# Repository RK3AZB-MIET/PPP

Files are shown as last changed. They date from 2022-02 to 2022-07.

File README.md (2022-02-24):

# Радиоприёмник прямого преобразования (приёмник Полякова)

Характеристики

Диапазон: 40 м (7000…7200 кГц), двухполосный приём (DSB)
Напряжение питания: 9 В («Крона»)
Ток потребления: ~15 мА
Выход: низкоомные наушники или малогабаритный динамик
Габариты: 100х50х75 мм (без выступающих ручек и разъёмов)

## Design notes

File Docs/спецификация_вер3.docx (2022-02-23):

СПЕЦИФИКАЦИЯ

ВЕРСИЯ 3.1

11

Наименование | Обозначение | Номинал | Кол-во

Конденсаторы
Конденсатор керамический 22пф 50V | C2 | 22pF | 1
Конденсатор керамический 100пф 50v NPO | C1, C7 | 100pF | 2
Конденсатор керамический 150пФ 50v NPO | C10 | 150pF | 1
Конденсатор керамический 180пф 50v М1500 | C8 | 180pF | 1
Конденсатор керамический 220пф 50V NPO | C1’, C2’ | 220pF | 2
Конденсатор керамический 4700пФ М1500 | C11 | 4700pF | 1
Конденсатор керамический 0.01мкф 50V X7R | C13 | 10nF | 1
Конденсатор керамический 0.047мкф 50v X7R | C9 | 47nF | 1
Конденсатор керамический 0.1мкф 50v Y5V | C3’, C3, C5, C6, C12, C16, C17, C18 | 100nF | 8
Конденсатор электролитический 10мкф 63V | C4, C14 | 10uF | 2
Конденсатор электролитический 100мкф 25V | C15 | 100uF | 1
Конденсатор электролитический 470мкф 16V | C20, C22 | 470uF | 2

Резисторы постоянные
Резистор 47 Ом 0.125Вт | R18 | 47 | 1
Резистор 470 Ом 0.25Вт | R14 | 470 | 1
Резистор 1.0 КОм 0.25Вт | R2’, R7 | 1k | 2
Резистор 2.0 КОм 0.25Вт | R10, R11, R12, R16 | 2k | 4
Резистор 3.3 кОм 0.25Вт | R2 | 3.3k | 1
Резистор 4.7 КОм 0.25Вт | R15, R19 | 4.7k | 2
Резистор 10 КОм 0.25Вт | R1 | 10k | 1
Резистор 15 КОм 0.25Вт | R1’ | 15k | 1
Резистор 20 КОм 0.25Вт | R6 | 20k | 1
Резистор 51 КОм 0.25Вт | R20 | 51k | 1
Резистор 100 КОм 0.25Вт | R5, R9 | 100k | 2
Резистор 200 КОм 0.25Вт | R8 | 200k | 1
Резистор 1 МОм 0.25Вт | R17 | 1M | 1
Резистор 2.2 МОм 0.25Вт | R17 | 2.2M | 1

Полупроводниковые приборы
BC547B (NPN 45V 0.1A 0.63W) TO-92 | VT1’, VT2, VT3, VT4, VT5 | | 5
BC557B (PNP 45V 0.1A 0.5W) TO-92 | VT1, VT6 | | 2
78L06ACZ Стабилизатор напряжения (+6В; 0.1А) TO-92 | DA1 | | 1
1N4148 (0.15A 100V) DO-35 | VD1, VD2 | | 2
1N4007 (1А 1000В) DO-41 | VD3 | | 1
Светодиод 3мм зеленый | - | | 1

Прочее
Батарейный отсек Крона BS-E провод 100мм | XP2 | | 1
Гнездо на плату 3.5мм CKX3-3.5-01 | XS1 | | 1
Разъем BNC гнездо на корпус | XT1 | | 1
Ручка приборная MF-B02 | - | | 1
Ручка приборная RR4836 зеленая (круг, 6мм) | - | | 2
Переменный резистор S16KN1-B 10K L15F с выключателем | R13 | 10k | 1
Переменный резистор 16K1 (WH148) 10k шлиц | R4 | 10k | 1
Переменный резистор 16K1 (WH148) 1k шлиц | R3 | 1k | 1
Кнопка тактовая 6*6*4.3 KAN0611-0431B | SB1*’ | | 1
Каркас катушки | L1, L2 | | 2
Резонатор кварцевый 7.000 МГц | ZQ1’ | | 1
B64290-L38-X38, T38, R10х6х4, Сердечник ферритовый кольцевой | L3 | | 1

ПЕРЕЧЕНЬ ИЗМЕНЕНИЙ

Обозначение | Наименование по спецификации | Наименование замены

СХЕМА ЭЛЕКТРИЧЕСКАЯ ПРИНЦИПИАЛЬНАЯ

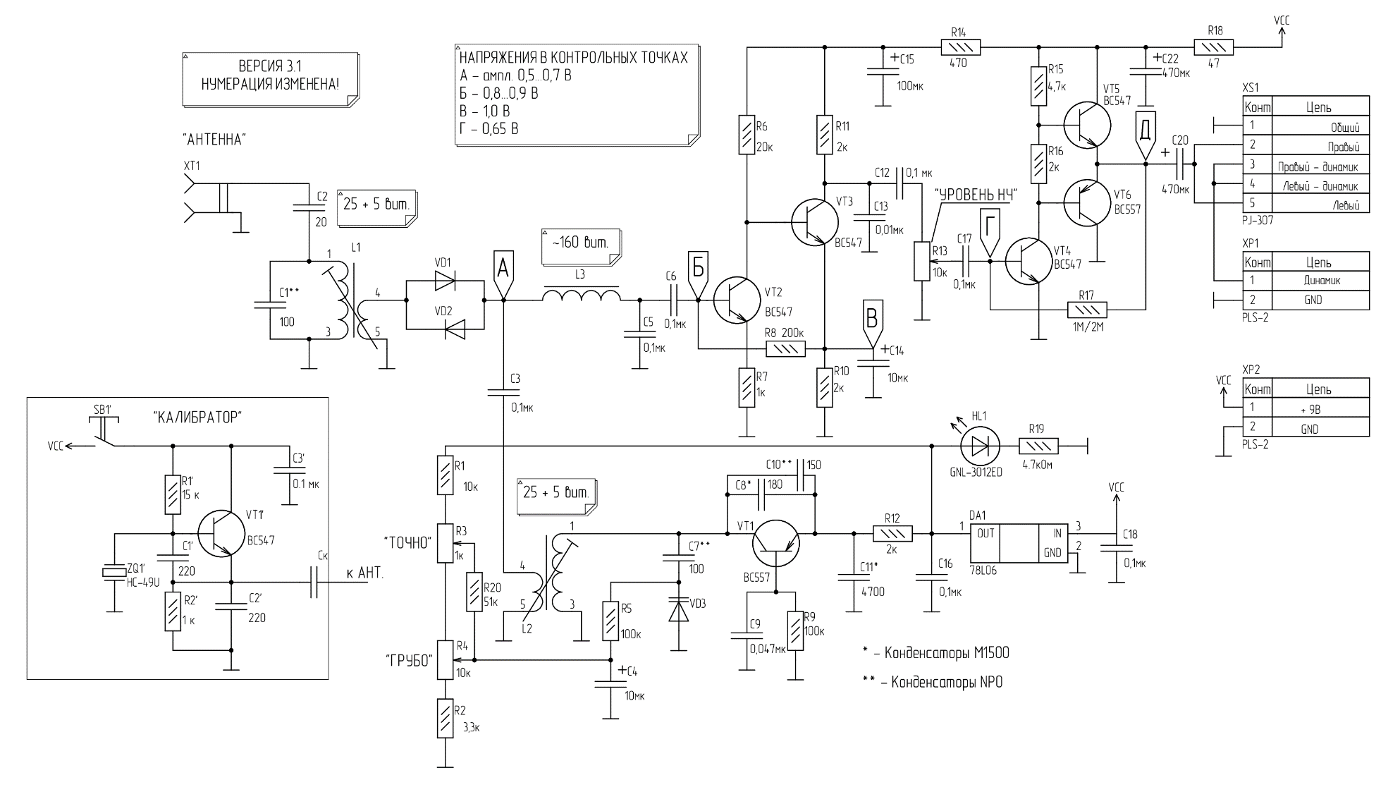
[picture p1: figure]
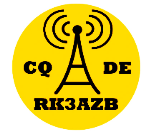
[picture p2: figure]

РАДИОКЛУБ МИЭТ г.ЗЕЛЕНОГРАД 73 DE RK3AZB!

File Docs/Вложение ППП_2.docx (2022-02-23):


Версия 3

РАДИОКЛУБ МИЭТ

РАДИОПРИЕМНИК ПРЯМОГО ПРЕОБРАЗОВАНИЯ

Перечень элементов

Обозначение | Номинал | Описание | Кол-во
C1, C2 | 180 или 220 | Конденсатор керамический | 2
C11, C16 | 0,01мк | Конденсатор керамический | 2
C12 | 180 | Конденсатор керамический М1500 | 1
C14 | 150 | Конденсатор керамический NP0 | 1
C13 | 0,047мк | Конденсатор керамический | 1
C15 | 4700 | Конденсатор керамический М1500 | 1
C17 | 47мк | Конденсатор электролитический | 1
C22, C23 | 470мк | Конденсатор электролитический | 2
C3 | 10 | Конденсатор керамический | 1
C4, C7, C9, C10, C19, C20, C21, C24 | 0,1мк | Конденсатор керамический | 8
C5 | 100 | Конденсатор керамический | 1
C6 | 22 | Конденсатор керамический | 1
C8 | 10мк | Конденсатор электролитический | 1
C18 | 100мк | Конденсатор электролитический | 1
DA1 | 78L06 | Стабилизатор напряжения | 1
L1, L2 | - | Катушка индуктивности подстроечная | 2
L3 | - | Катушка индуктивности | 1
R1 | 15к | Резистор | 1
R11, R12, R13, R17 | 2к | Резистор | 4
R15 | 470 | Резистор | 1
R16 | 4,7к | Резистор | 1
R18 | 2,2М | Резистор | 1
R19 | 47 | Резистор | 1
R2, R3, R8 | 1к | Резистор | 3
R4 | 1к | Резистор переменный | 1
R5 | 10к | Резистор переменный | 1
R14 | 10к | Резистор переменный с выключателем | 1
R6, R10 | 100к | Резистор | 2
R7 | 20к | Резистор | 1
R9 | 200к | Резистор | 1
SB1 | KLS7-TS6601 | Кнопка тактовая | 1
VD1, VD2 | 1N4148 | Диод | 2
VD3, VD4 | BB133 | Варикап | 2
VT1, VT3, VT4, VT5, VT6 | BC547 | Транзистор биполярный | 5
VT2, VT7 | BC557 | Транзистор биполярный | 2
XP1, XP2* | PLS-2 | Вилка штыревая | 2
XS1 | PJ-307 | Розетка | 1
XT1* | DG128-5.0-02P-14 | Соединитель | 1
ZQ1 | 7 (7.03) MГц | Резонатор кварцевый | 1

Дополнительно: розетка BNC, рукоятки малые (2 шт), рукоятка большая, колодка батарейная, светодиод, резистор 4,7к для светодиода

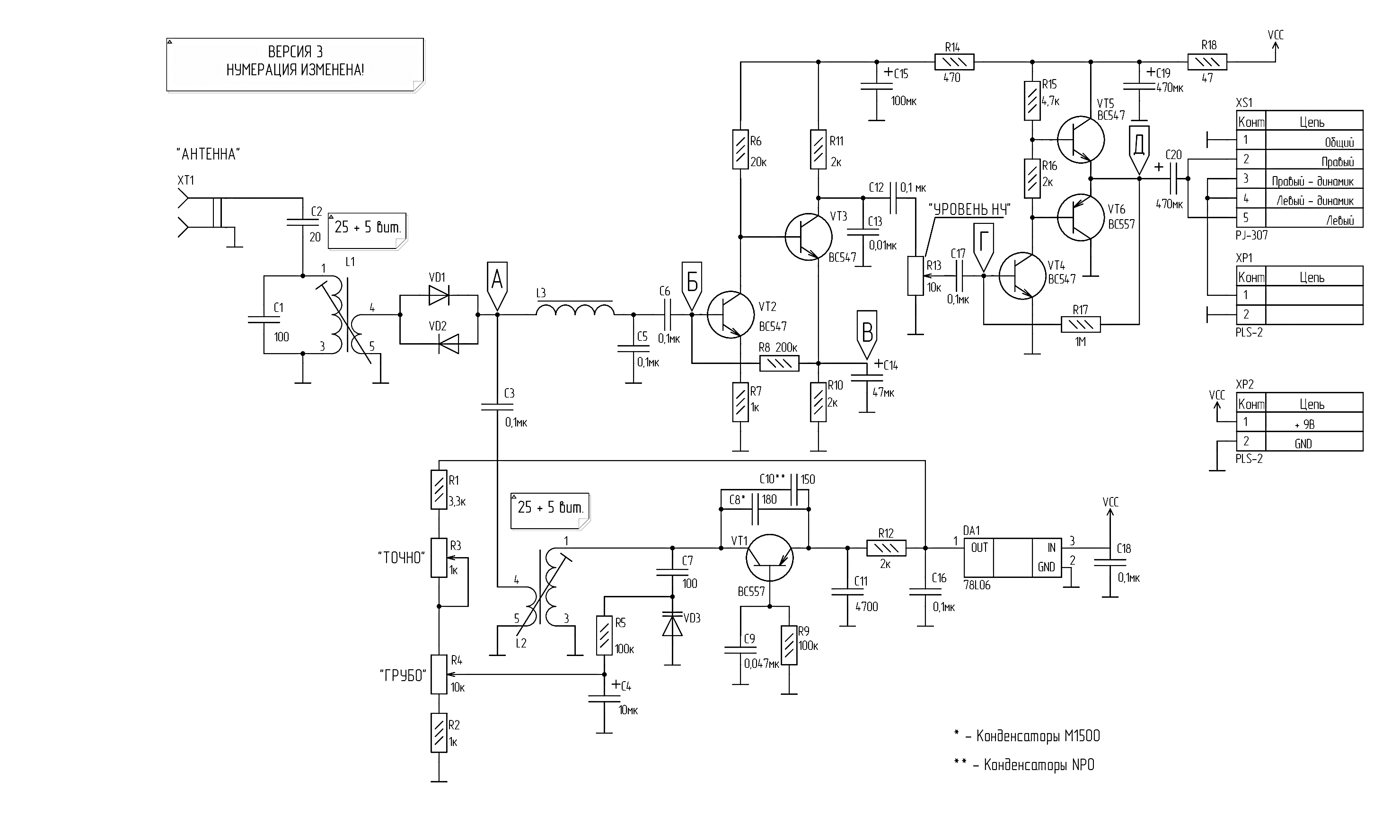
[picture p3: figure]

Схема базовая.

Версия 3

Напряжения в контр. точках

A | ампл. 0,5…0,7 В
Б | 0,8…0,9 В
B | 1,0…1,1 В
Г | 0,65 В
Д | 4,5 В

Благодарим вас за внимание к нашему проекту! Желаем получить удовольствие от сборки и наладки приемника. 73 de R2DNN, R3YAB

Схема калибратора.

Схема шкалы цифровой.

Замена ЭРИ

Поз. обозначение | Номинал в схеме | Замена

__________ * - не комплектовать

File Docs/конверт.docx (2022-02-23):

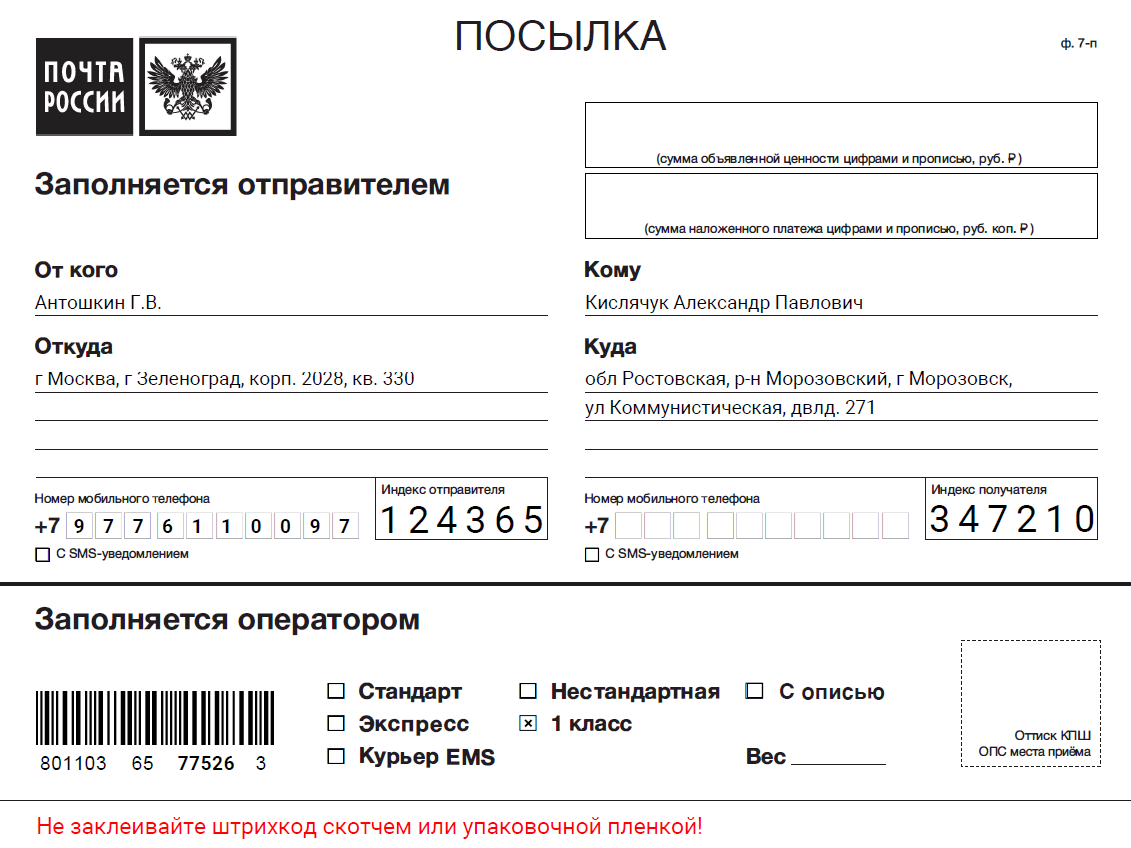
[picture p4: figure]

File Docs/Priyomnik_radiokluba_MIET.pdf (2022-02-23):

РАДИОКЛУБ МИЭТ

## Радиоприемник прямого преобразования

## (Радиоприёмник В.Т. Полякова)

Инструкция по сборке и наладке

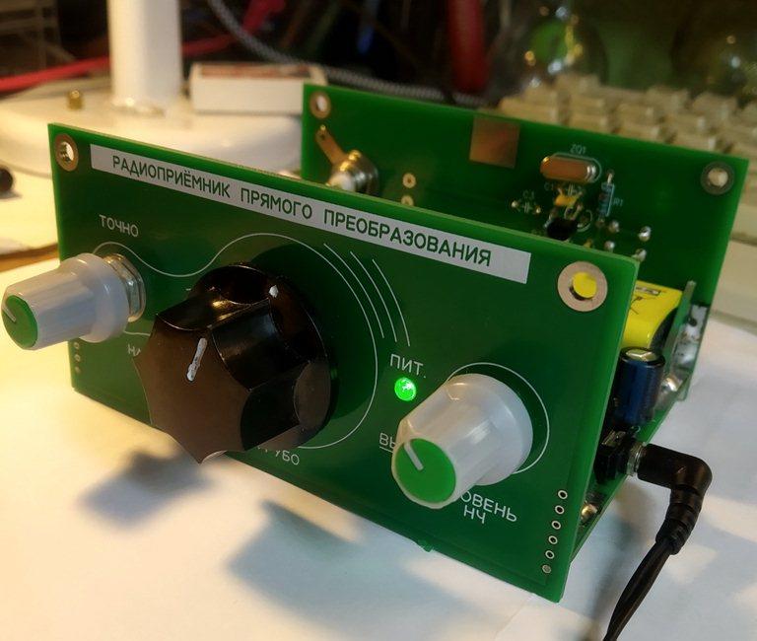
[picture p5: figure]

Зеленоград 2020

Здравствуйте!

Итак, Вы получили комплект для сборки приёмника прямого преобразования радиоклуба МИЭТ. Здесь мы опишем его схему, шаги по сборке и настройке.

Характеристики

Диапазон: 40 м (7000…7200 кГц), двухполосный приём (DSB)

Напряжение питания: 9 В («Крона»)

Ток потребления: ~15 мА

Выход: низкоомные наушники или малогабаритный динамик

Схема

Приёмник сделан на основе классических схем прямого преобразования [1, 2]. Гетеродин - плавного диапазона (ГПД) с регулировкой варикапами.

В колебательный контур гетеродина входят L2 (первичная обмотка) и (VD3+VD4)–C11–(C12+C14)–C15, причем цепочки емкостей (VD3+VD4)–C11 и (C12+C14)–C15 входят в контур параллельно. Ёмкость контура определяют VD3+VD4 (переменная часть) и C12+C14 (постоянная часть). Цепочка резисторов R3-R5-R4 создает отрицательное смещение на варикапах VD3+VD4 и позволяет регулировать частоту – грубо и плавно. Гетеродин настроен на половинную частоту диапазона и перестраивается от 3500 до 3600 кГц с небольшим запасом сверху и снизу. Питание гетеродина 6 В стабилизировано DA1 и блокировочными конденсаторами C19 и С21.

Простой входной контур L1C5 связан с антенной через небольшую ёмкость C6 и со смесителем через вторичную обмотку L1 – так согласовывается высокое сопротивление контура с низким сопротивлением смесителя и антенны.

Смеситель на встречно-параллельных диодах VD1-VD2 (1N4148) позволяет выделять разностную частоту между частотой сигнала и удвоенной частотой гетеродина.

Через конденсатор C7 сигнал гетеродина со вторичной обмотки L2 поступает на смеситель, и тот же C7 входит в состав фильтра низкой частоты (ФНЧ) C7L3C9 с частотой среза около 3 кГц, что позволяет комфортно слушать SSB станции.

УНЧ состоит из предусилителя (VT3-VT4) и усилителя мощности (VT5-VT6-VT7), разделённых регулятором громкости. Выход и вход предусилителя связан отрицательной обратной связью (ООС) R9, которая выставляет режим транзисторов по постоянному току. Конденсатор C17 ослабляет ООС по звуковой частоте, что поднимает коэффициент усиления. Конденсатор C16 вместе с выходным сопротивлением предусилителя и регулятором громкости R14 образует дополнительный ФНЧ, ослабляя мешающие сигналы в районе нескольких килогерц.

После регулятора громкости сигнал усиливается усилителем мощности на двух каскадах, причём второй каскад – эмиттерный повторитель на транзисторах разной проводимости. С точки соединения эмиттеров VT6 и VT7 сигнал, с одной стороны, поступает через R18 на вход, образуя ООС усилителя мощности (так образуется смещение на базе транзистора VT5), а, с другой – идёт на низкоомную нагрузку через разделительный конденсатор C23. Цепочки C18 R15, C22 R19 развязывают по питанию каскады УНЧ друг от друга и от гетеродина, препятствуя самовозбуждению.

Детали и наладка

Прежде всего собирают УНЧ и проверяют его работу, подключив наушники и включив питание через миллиамперметр. Нормально работающий УНЧ должен потреблять около 10 мА, при этом в наушниках должен быть слышен белый шум. Если коснуться пинцетом входа УНЧ (левый по схеме вывод C20), в наушниках будет громкий фон 50 Гц. Вольтметром измеряется напряжение в точке Д соединения эмиттеров VT6–VT7 – оно должно быть равно половине напряжения питания. Также проверяются контрольные напряжения в точках Б (0,8…0,9 В), В (1,0 В), Г (0,65 В). Если при работающем УНЧ ток покоя значительно больше 10 мА (20…30 мА), то стоит его уменьшить, увеличив значение резистора R18, например, до 2 МОм. Поскольку схема и конструкция приёмника рассчитаны на маломощную «Крону», то лучше сделать приёмник максимально экономичным. Выходной каскад VT6–VT7 является главным потребителем тока в приёмнике, и коэффициент усиления этих транзисторов, во-первых, должен быть примерно одинаков, а, во-вторых, он совместно с R18 и определяет потребляемый ток.

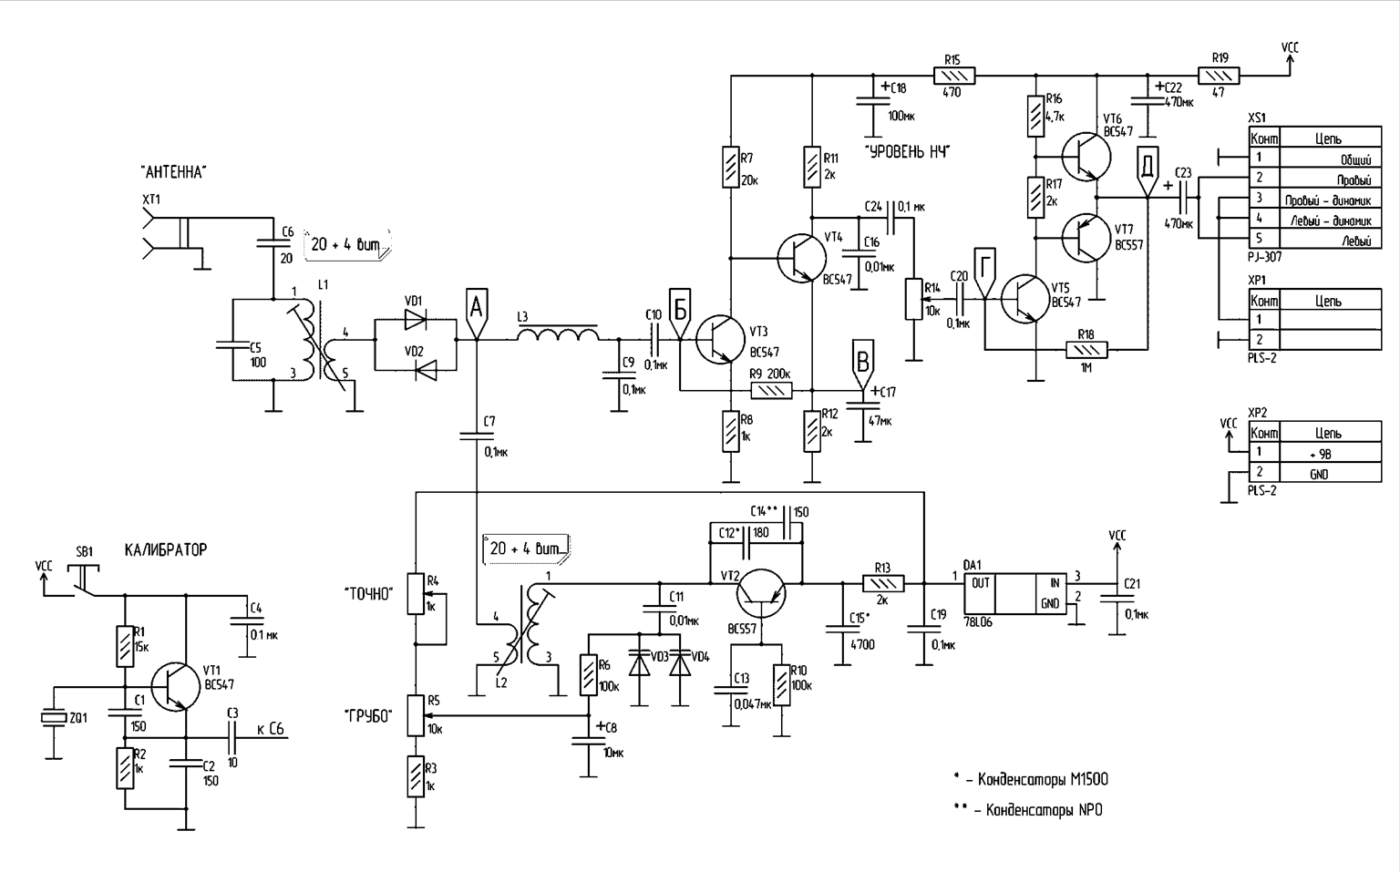
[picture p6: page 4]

4

Рис. 1. Схема электрическая принципиальная

Усиление УНЧ получается с запасом, его хватает и на работу динамика. Если всё же предполагается использовать наушники, а сигнал получается слишком громким и/или усилитель самовозбуждается, рекомендуем заменить значение R8 на большее, например, 2…4,7 кОм – это снизит коэффициент усиления.

Дроссель L3 наматывают на входящем в набор ферритовом сердечнике с проницаемостью 10000 размером 10х6х4. С помощью челнока наматывают 200 витков (это соответствует индуктивности 0,16 Гн). Еще один вариант -использовать головку от магнитофона. Также интересны недавно появившиеся сердечники из аморфного железа (см. статью [3]), тогда число витков будет сильно меньше. L4 закрепляют на плате термоклеем.

Затем можно приступать к гетеродину, смесителю и входному контуру. Катушки L1 и L2 – одинаковые, они наматываются на каркасах диаметром 5 мм с ферритовым подстроечным сердечником эмалированным проводом 0,11 мм (намоточный провод длиной 3 м входит в комплект – его хватает на L1, L2 и L3). Для первичной обмотки 20 витков, для вторичной – 4 витка. Первичную катушку лучше мотать виток к витку, туго прижимая витки к каркасу и друг к другу. Крайние витки можно закреплять нитками, а можно воспользоваться хитростями промышленных технологий ручной намотки (рис. 2): вырезается тонкая полоска плотной бумаги шириной примерно 1 мм и длиной около 2 см. Прежде чем намотать первый виток на катушку, один виток провода завязывают вокруг это полоски у ее края. Прикладывают эту полоску к катушке – вдоль каркаса, так чтобы маленькая петля была у основания катушки – так закрепляется первый виток. Затем плотно наматывают первичную катушку, начиная от этой петельки, чтобы полоска бумаги была плотно прижата намоткой к каркасу. Последний виток также закрепляют в виде петельки вокруг бумажной полоски. Аналогично делают вторичную обмотку на расстоянии 1…2 миллиметров от первичной. В конце желательно закрепить обмотки парафином, лишние хвостики бумажной полоски обрезают.

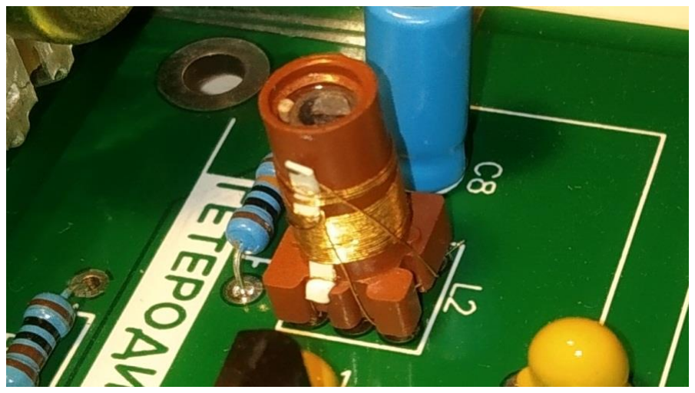
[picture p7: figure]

Рис. 2. Фиксация намотки на каркасе.

Довольно тонкой работы требуют SMD варикапы BB133 (рис. 3), они паяются снизу основной платы. Перед пайкой стоит определить их полярность мультиметром в режиме проверки диодов. При пайке лучше использовать лупу и тонкий пинцет.

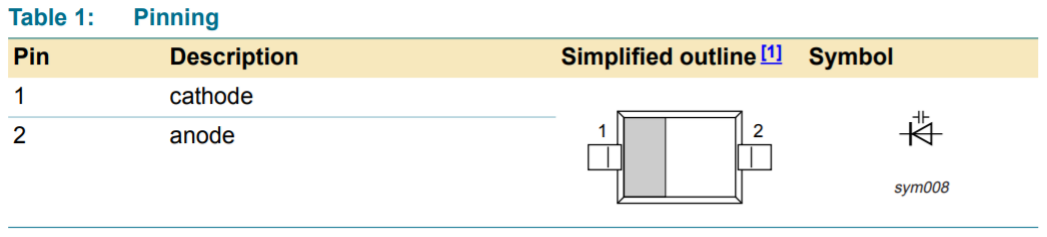
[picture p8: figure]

Рис. 3. Расположение выводов варикапа BB133

После того, как приёмник спаян полностью, проверяют работу гетеродина с помощью осциллографа (при его наличии), либо сделав простейший пробник из германиевого диода, последовательно соединенного с вольтметром – так можно оценивать амплитуду переменного напряжения в различных точках схемы. В точке А измеряют амплитуду переменного напряжения – оно должно быть около 0,5…0,7 В (среднее значение должно быть равно 0).

Далее необходимо отрегулировать рабочий диапазон гетеродина. Можно воспользоваться осциллографом или частотомером, но удобнее использовать калибратор с кварцевой стабилизацией на 7000 кГц в составе приёмника (см. схему). При вывернутых влево ручках настройки собираемого приёмника (нижний край диапазона) вращением сердечника катушки L2 находят частоту 7000 кГц (частота гетеродина 3500 кГц).

Затем поворачиваем ручку грубой настройки вправо – смотрим, какая частота получается. В идеале должно быть около 7220…7240 кГц (оставляем по десять-двадцать килогерц запас сверху и снизу). Верхний край диапазона можно найти в вечернее время с подключенной антенной – сразу после любительского диапазона начинается вещательный диапазон, на нижнем краю которого (начиная с 7205 кГц) обычно работают громкие вещательные станции. Ширину диапазона можно сделать такой, чтобы можно было настроиться на несущую одной из таких станций.

Если диапазон получается слишком широким или слишком узким, надо подобрать значение конденсаторов C12 и C14. Ещё один способ регулировки ширины диапазона: изменить значение эмиттерного резистора R13. Дело в том, что при этом будет меняться амплитуда сигнала гетеродина, а она будет влиять на эффективную ёмкость варикапов: чем больше R13, тем меньше амплитуда, и тем больше эффективный интервал перестройки варикапов, шире диапазон. В пределах амплитуды 0,5…0,7 вольт в точке А смеситель будет работать хорошо, и некоторый запас в вариации амплитуды гетеродина обычно есть. И, наконец, можно также увеличить значение сопротивления R3 до нескольких килоом в случае слишком широкого диапазона.

Обратите внимание: в комплект входят конденсаторы колебательного контура гетеродина с нормируемыми ТКЕ (температурный коэффициент ёмкости). Варикапы и катушка имеют положительный температурный коэффициент, и их надо компенсировать отрицательными ТКЕ C12-C14. Для этого в двух из них стоит ТКЕ М1500 (-1500 ppm на градус), а в третьем NP0 (нулевой температурный коэффициент).

При желании можно измерить такой параметр приёмника, как уход частоты при изменении температуры. Проверять этот параметр лучше после того, как приёмник остынет после пайки. Потребуется термометр, небольшая картонная коробка и какой-либо источник тепла либо холода. Включённый приёмник вместе с термометром закрывают в коробку и дают частоте и температуре внутри застабилизироваться вдали от источника тепла или холода. Замечают частоту гетеродина внешним приёмником, и записывают температуру. Затем переносят коробку на подоконник (если на улице холодно) или ставят на нагреватель, и дожидаются установки новой стабильной частоты и новой стабильной
температуры. | Достаточно | перепада | температуры | около | 10 | °C. | Для
использования приёмника в домашних условиях желательно добиться, чтобы частота уходила не больше нескольких сотен Гц/°C. Значения вложенных в набор конденсаторов C12-C14 удовлетворяют этим требованиям.

В конце, подключив антенну, регулируют входной контур подстройкой ферритового сердечника L1 по максимуму громкости сигнала или шума в середине диапазона, затем еще раз точно выставляют начало диапазона катушкой L2, и отладка приёмника завершена.

Конструкция и порядок сборки

Приёмник выполнен в виде трёх плат, которые собираются пайкой в жёсткую конструкцию. Сначала собирают основную плату, проверяют работу УНЧ и гетеродина – эти узлы начинают работать и без переменных резисторов. Затем собирают переднюю панель – прикручивают переменные резисторы (R14 – с выключателем) и припаивают их ножки к контактам на плате (ножки нужно пригнуть к плате пинцетом). Светодиод припаивают к контактным площадкам и соединяют анод через резистор 4.7К к выключателю питанию на потенциометре громкости R14, к тому же контакту выключателя идёт провод к «+» XP2 на основной плате. Плюсовой вывод от батареи питания припаивают ко второму контакту выключателя, минусовой – к «-» XP2. Передняя панель припаивается снизу контактными площадками.

Затем собирается калибратор, прикручивается антенный разъём, припаивается его центральный контакт коротким проводом к контакту X1 на плате, и задняя панель также припаивается снизу контактами к основной плате. В таком положении приёмник можно настраивать, а при крайней необходимости переднюю и заднюю платы несложно отпаять.

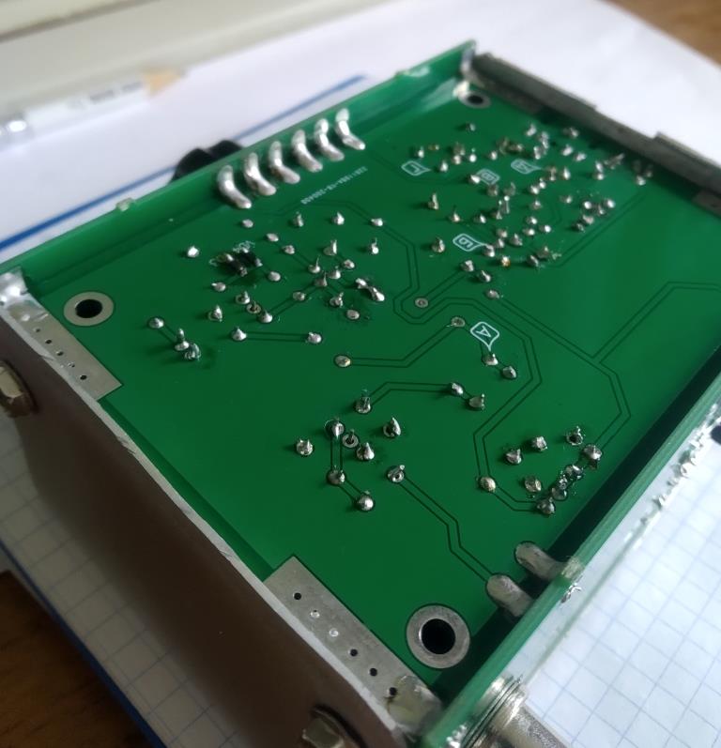
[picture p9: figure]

Рис. 4. Вид снизу на монтаж радиоприемника.

Наконец, после окончательной настройки на диапазон выравнивают положение плат друг относительно друга (под углом 90˚) и припаивают уголки. «Крону» можно прикрепить к основной плате двусторонним скотчем.

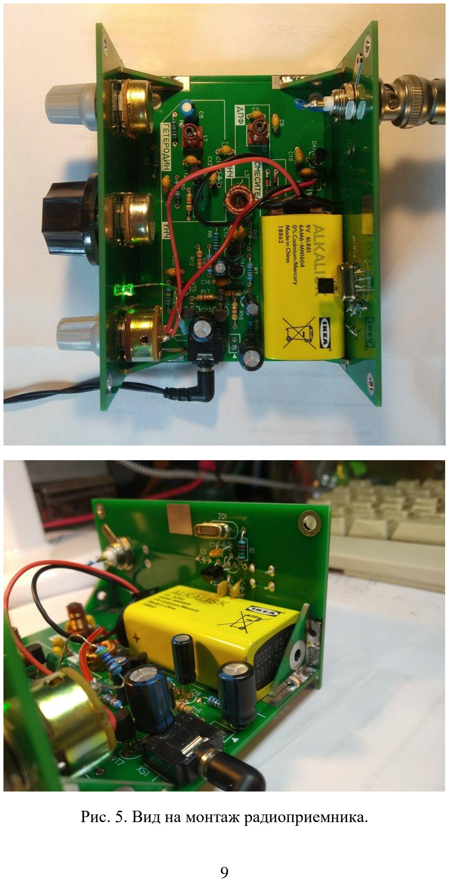
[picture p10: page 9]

Рис. 5. Вид на монтаж радиоприемника.

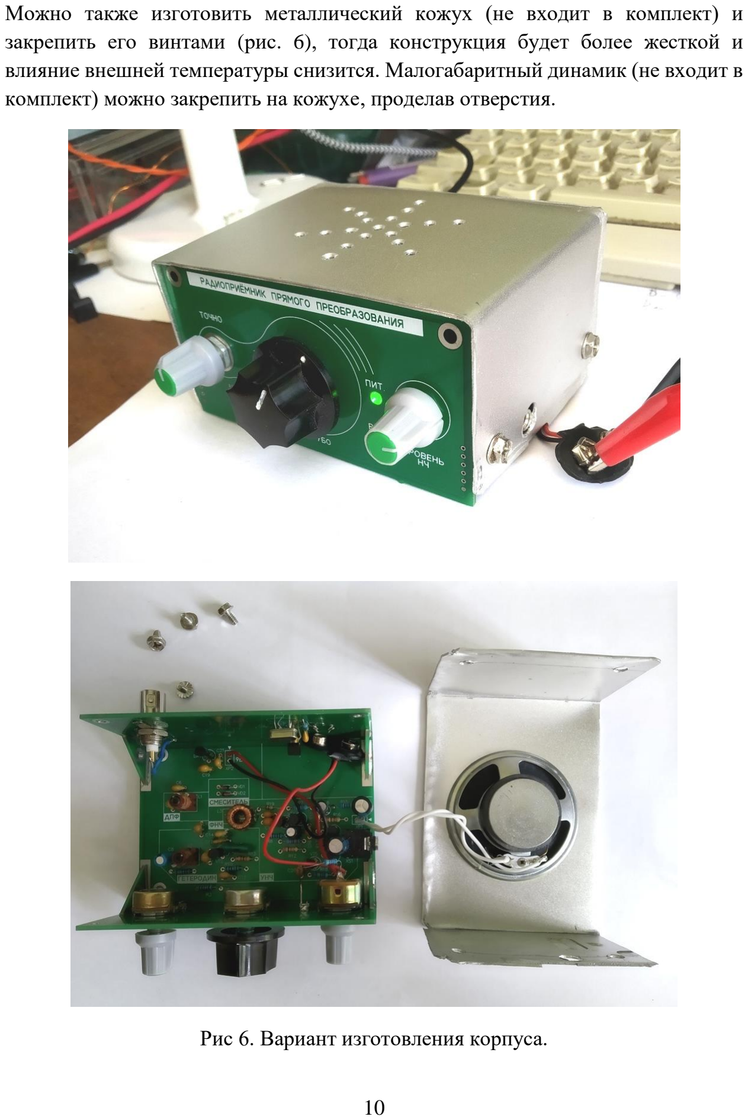
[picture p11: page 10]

Можно также изготовить металлический кожух (не входит в комплект) и закрепить его винтами (рис. 6), тогда конструкция будет более жесткой и влияние внешней температуры снизится. Малогабаритный динамик (не входит в комплект) можно закрепить на кожухе, проделав отверстия.

Рис 6. Вариант изготовления корпуса.

Благодарим вас за внимание к нашему проекту! Желаем получить удовольствие от сборки и наладки приемника. 73!

С любыми вопросами обращайтесь:

Влад Жигалов (R2DNN) zhigalov@gmail.com

Герман Антошкин (R3YAB) r3yab@mail.ru

Радиоклуб МИЭТ (RK3AZB) https://vk.com/rk3azb

Литература:

1. В.Т. Поляков. Радиолюбителям о технике прямого преобразования (1990). http://qrp.ru/files/literature/category/10-ra3aaedocs?download=247%3Adc
2. В.Т. Поляков. Приемник прямого преобразования для "охоты на лис", журнал "Радио" за 1982 год, №4, стр. 49-52; №7, стр.54, 55. http://qrp.ru/files/literature/category/10-ra3aaedocs?download=376%3Afoxhuntdcrra3aae (http://qrp.ru/files/literature/category/10-ra3aaedocs?download=376%3Afoxhuntdcrra3aae)
3. Д. Горох. Применение сердечников из аморфного железа. CQ-QRP#70 (Весна 2020). http://qrp.ru/cqqrp-magazine/1536-cq-qrp-70
4. Тема про данный приёмник на форуме клуба RU-QRP: RU-QRP Club forum :: Тема: Приёмник ППП радиоклуба МИЭТ (http://qrp.ru/forum/9-%D0%A1%D0%B0%D0%BC%D0%BE%D0%B4%D0%B5%D0%BB%D1%8C%D0%BD%D0%B0%D1%8F-%D1%82%D0%B5%D1%85%D0%BD%D0%B8%D0%BA%D0%B0/13210-%D0%9F%D1%80%D0%B8%D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)

Приложение. Перечень элементов

Обозначение | Номинал | Описание | Кол-во
C1, C2 | 180 или 220 | Конденсатор керамический | 2
C11, C16 | 0.01мк | Конденсатор керамический | 2
C12 | 180 | Конденсатор керамический М1500 | 1
C14 | 150 | Конденсатор керамический NP0 | 1
C13 | 0,047мк | Конденсатор керамический | 1
C15 | 4700 | Конденсатор керамический М1500 | 1
C17 | 47мк | Конденсатор электролитический | 1
C22, C23 | 470мк | Конденсатор электролитический | 2
C3 | 10 | Конденсатор керамический | 1
C4, C7, C9, C10, C19, C20, C21, C24 | 0.1мк | Конденсатор керамический | 8
C5 | 100 | Конденсатор керамический | 1
C6 | 22 | Конденсатор керамический | 1
C8 | 10мк | Конденсатор электролитический | 1
C18 | 100мк | Конденсатор электролитический | 1
DA1 | 78L06 | Стабилизатор напряжения | 1
L1, L2 | - | Катушка индуктивности подстроечная | 2
L3 | - | Катушка индуктивности | 1
R1 | 15к | Резистор | 1
R11, R12, R13, R17 | 2к | Резистор | 4
R15 | 470 | Резистор | 1
R16 | 4.7к | Резистор | 1
R18 | 1М или 2М | Резистор | 1
R19 | 47 | Резистор | 1
R2, R3, R8 | 1к | Резистор | 3
R4 | 1к | Резистор переменный | 1
R5, R14 | 10к | Резистор переменный c выключателем | 2
R6, R10 | 100к | Резистор | 2
R7 | 20к | Резистор | 1
R9 | 200к | Резистор | 1
SB1 | KLS7-TS6601 | Кнопка тактовая | 1
VD1, VD2 | 1N4148 | Диод | 2
VD3, VD4 | BB133 | Варикап | 2
VT1, VT3, VT4, VT5, VT6 | BC547 | Транзистор биполярный | 5
VT2, VT7 | BC557 | Транзистор биполярный | 2
XP1, XP2* | PLS-2 | Вилка штыревая | 2
XS1 | PJ-307 | Розетка | 1
XT1* | DG128-5.0-02P-14 | Соединитель | 1
ZQ1 | 7 MHz | Резонатор кварцевый | 1
* - не комплектуются

Дополнительно: розетка BNC, рукоятки малые (2 шт), рукоятка большая, колодка батарейная, светодиод, резистор 4,7к для светодиода.

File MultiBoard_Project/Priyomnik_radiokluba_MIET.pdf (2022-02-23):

РАДИОКЛУБ МИЭТ

## Радиоприемник прямого преобразования

## (Радиоприёмник В.Т. Полякова)

Инструкция по сборке и наладке


Зеленоград 2020

Добрый день!

Итак, Вы получили комплект для сборки приёмника прямого преобразования радиоклуба МИЭТ. Здесь мы опишем его схему, шаги по сборке и настройке.

Характеристики

Диапазон: 40 м (7000…7200 кГц), двухполосный приём (DSB)

Напряжение питания: 9 В («Крона»)

Ток потребления: ~15 мА

Выход: низкоомные наушники или малогабаритный динамик

Схема

Приёмник сделан на основе классических схем прямого преобразования [1, 2]. Гетеродин - плавного диапазона (ГПД) с регулировкой варикапами.

В колебательный контур гетеродина входят L2 (первичная обмотка) и (VD3+VD4)–C11–(C12+C14)–C15, причем цепочки емкостей (VD3+VD4)–C11 и (C12+C14)–C15 входят в контур параллельно. Ёмкость контура определяют VD3+VD4 (переменная часть) и C12+C14 (постоянная часть). Цепочка резисторов R3-R5-R4 создает отрицательное смещение на варикапах VD3+VD4 и позволяет регулировать частоту – грубо и плавно. Гетеродин настроен на половинную частоту диапазона и перестраивается от 3500 до 3600 кГц с небольшим запасом сверху и снизу. Питание гетеродина 6 В стабилизировано DA1 и блокировочными конденсаторами C19 и С21.

Простой входной контур L1C5 связан с антенной через небольшую ёмкость C6 и со смесителем через вторичную обмотку L1 – так согласовывается высокое сопротивление контура с низким сопротивлением смесителя и антенны.

Смеситель на встречно-параллельных диодах VD1-VD2 (1N4148) позволяет выделять разностную частоту между частотой сигнала и удвоенной частотой гетеродина.

Через конденсатор C7 сигнал гетеродина со вторичной обмотки L2 поступает на смеситель, и тот же C7 входит в состав фильтра низкой частоты (ФНЧ) C7L3C9 с частотой среза около 3 кГц, что позволяет комфортно слушать SSB станции.

УНЧ состоит из предусилителя (VT3-VT4) и усилителя мощности (VT5-VT6-VT7), разделённых регулятором громкости. Выход и вход предусилителя связан отрицательной обратной связью (ООС) R9, которая выставляет режим транзисторов по постоянному току. Конденсатор C17 ослабляет ООС по звуковой частоте, что поднимает коэффициент усиления. Конденсатор C16 вместе с выходным сопротивлением предусилителя и регулятором громкости R14 образует дополнительный ФНЧ, ослабляя мешающие сигналы в районе нескольких килогерц.

После регулятора громкости сигнал усиливается усилителем мощности на двух каскадах, причём второй каскад – эмиттерный повторитель на транзисторах разной проводимости. С точки соединения эмиттеров VT6 и VT7 сигнал, с одной стороны, поступает через R18 на вход, образуя ООС усилителя мощности (так образуется смещение на базе транзистора VT5), а, с другой – идёт на низкоомную нагрузку через разделительный конденсатор C23. Цепочки C18 R15, C22 R19 развязывают по питанию каскады УНЧ друг от друга и от гетеродина, препятствуя самовозбуждению.

Детали и наладка

Прежде всего собирают УНЧ и проверяют его работу, подключив наушники и включив питание через миллиамперметр. Нормально работающий УНЧ должен потреблять около 10 мА, при этом в наушниках должен быть слышен белый шум. Если коснуться пинцетом входа УНЧ (левый по схеме вывод C20), в наушниках будет громкий фон 50 Гц. Вольтметром измеряется напряжение в точке Д соединения эмиттеров VT6–VT7 – оно должно быть равно половине напряжения питания. Также проверяются контрольные напряжения в точках Б (0,8…0,9 В), В (1,0 В), Г (0,65 В). Если при работающем УНЧ ток покоя значительно больше 10 мА (20…30 мА), то стоит его уменьшить, увеличив значение резистора R18, например, до 2 МОм. Поскольку схема и конструкция приёмника рассчитаны на маломощную «Крону», то лучше сделать приёмник максимально экономичным. Выходной каскад VT6–VT7 является главным потребителем тока в приёмнике, и коэффициент усиления этих транзисторов, во-первых, должен быть примерно одинаков, а, во-вторых, он совместно с R18 и определяет потребляемый ток.


4

5

Рис. 1. Схема электрическая принципиальная

Усиление УНЧ получается с запасом, его хватает и на работу динамика. Если всё же предполагается использовать наушники, а сигнал получается слишком громким и/или усилитель самовозбуждается, рекомендуем заменить значение R8 на большее, например, 2…4,7 кОм – это снизит коэффициент усиления.

Дроссель L3 наматывают на входящем в набор ферритовом сердечнике с проницаемостью 10000 размером 10х6х4. С помощью челнока наматывают 200 витков (это соответствует индуктивности 0,16 Гн). Еще один вариант -использовать головку от магнитофона. Также интересны недавно появившиеся сердечники из аморфного железа (см. статью [3]), тогда число витков будет сильно меньше. L4 закрепляют на плате термоклеем.

Затем можно приступать к гетеродину, смесителю и входному контуру. Катушки L1 и L2 – одинаковые, они наматываются на каркасах диаметром 5 мм с ферритовым подстроечным сердечником эмалированным проводом 0,11 мм (намоточный провод длиной 3 м входит в комплект – его хватает на L1, L2 и L3). Для первичной обмотки 20 витков, для вторичной – 4 витка. Первичную катушку лучше мотать виток к витку, туго прижимая витки к каркасу и друг к другу. Крайние витки можно закреплять нитками, а можно воспользоваться хитростями промышленных технологий ручной намотки (рис. 2): вырезается тонкая полоска плотной бумаги шириной примерно 1 мм и длиной около 2 см. Прежде чем намотать первый виток на катушку, один виток провода завязывают вокруг это полоски у ее края. Прикладывают эту полоску к катушке – вдоль каркаса, так чтобы маленькая петля была у основания катушки – так закрепляется первый виток. Затем плотно наматывают первичную катушку, начиная от этой петельки, чтобы полоска бумаги была плотно прижата намоткой к каркасу. Последний виток также закрепляют в виде петельки вокруг бумажной полоски. Аналогично делают вторичную обмотку на расстоянии 1…2 миллиметров от первичной. В конце желательно закрепить обмотки парафином, лишние хвостики бумажной полоски обрезают.


Рис. 2. Фиксация намотки на каркасе.

Довольно тонкой работы требуют SMD варикапы BB133 (рис. 3), они паяются снизу основной платы. Перед пайкой стоит определить их полярность мультиметром в режиме проверки диодов. При пайке лучше использовать лупу и тонкий пинцет.


Рис. 3. Расположение выводов варикапа BB133

После того, как приёмник спаян полностью, проверяют работу гетеродина с помощью осциллографа (при его наличии), либо сделав простейший пробник из германиевого диода, последовательно соединенного с вольтметром – так можно оценивать амплитуду переменного напряжения в различных точках схемы. В точке А измеряют амплитуду переменного напряжения – оно должно быть около 0,5…0,7 В (среднее значение должно быть равно 0).

Далее необходимо отрегулировать рабочий диапазон гетеродина. Можно воспользоваться осциллографом или частотомером, но удобнее использовать калибратор с кварцевой стабилизацией на 7000 кГц в составе приёмника (см. схему). При вывернутых влево ручках настройки собираемого приёмника (нижний край диапазона) вращением сердечника катушки L2 находят частоту 7000 кГц (частота гетеродина 3500 кГц).

Затем поворачиваем ручку грубой настройки вправо – смотрим, какая частота получается. В идеале должно быть около 7220…7240 кГц (оставляем по десять-двадцать килогерц запас сверху и снизу). Верхний край диапазона можно найти в вечернее время с подключенной антенной – сразу после любительского диапазона начинается вещательный диапазон, на нижнем краю которого (начиная с 7205 кГц) обычно работают громкие вещательные станции. Ширину диапазона можно сделать такой, чтобы можно было настроиться на несущую одной из таких станций.

Если диапазон получается слишком широким или слишком узким, надо подобрать значение конденсаторов C12 и C14. Ещё один способ регулировки ширины диапазона: изменить значение эмиттерного резистора R13. Дело в том, что при этом будет меняться амплитуда сигнала гетеродина, а она будет влиять на эффективную ёмкость варикапов: чем больше R13, тем меньше амплитуда, и тем больше эффективный интервал перестройки варикапов, шире диапазон. В пределах амплитуды 0,5…0,7 вольт в точке А смеситель будет работать хорошо, и некоторый запас в вариации амплитуды гетеродина обычно есть. И, наконец, можно также увеличить значение сопротивления R3 до нескольких килоом в случае слишком широкого диапазона.

Обратите внимание: в комплект входят конденсаторы колебательного контура гетеродина с нормируемыми ТКЕ (температурный коэффициент ёмкости). Варикапы и катушка имеют положительный температурный коэффициент, и их надо компенсировать отрицательными ТКЕ C12-C14. Для этого в двух из них стоит ТКЕ М1500 (-1500 ppm на градус), а в третьем NP0 (нулевой температурный коэффициент).

При желании можно измерить такой параметр приёмника, как уход частоты при изменении температуры. Проверять этот параметр лучше после того, как приёмник остынет после пайки. Потребуется термометр, небольшая картонная коробка и какой-либо источник тепла либо холода. Включённый приёмник вместе с термометром закрывают в коробку и дают частоте и температуре внутри застабилизироваться вдали от источника тепла или холода. Замечают частоту гетеродина внешним приёмником, и записывают температуру. Затем переносят коробку на подоконник (если на улице холодно) или ставят на нагреватель, и дожидаются установки новой стабильной частоты и новой стабильной
температуры. | Достаточно | перепада | температуры | около | 10 | °C. | Для
использования приёмника в домашних условиях желательно добиться, чтобы частота уходила не больше нескольких сотен Гц/°C. Значения вложенных в набор конденсаторов C12-C14 удовлетворяют этим требованиям.

В конце, подключив антенну, регулируют входной контур подстройкой ферритового сердечника L1 по максимуму громкости сигнала или шума в середине диапазона, затем еще раз точно выставляют начало диапазона катушкой L2, и отладка приёмника завершена.

Конструкция и порядок сборки

Приёмник выполнен в виде трёх плат, которые собираются пайкой в жёсткую конструкцию. Сначала собирают основную плату, проверяют работу УНЧ и гетеродина – эти узлы начинают работать и без переменных резисторов. Затем собирают переднюю панель – прикручивают переменные резисторы (R14 – с выключателем) и припаивают их ножки к контактам на плате (ножки нужно пригнуть к плате пинцетом). Светодиод припаивают к контактным площадкам и соединяют анод через резистор 4.7К к выключателю питанию на потенциометре громкости R14, к тому же контакту выключателя идёт провод к «+» XP2 на основной плате. Плюсовой вывод от батареи питания припаивают ко второму контакту выключателя, минусовой – к «-» XP2. Передняя панель припаивается снизу контактными площадками.

Затем собирается калибратор, прикручивается антенный разъём, припаивается его центральный контакт коротким проводом к контакту X1 на плате, и задняя панель также припаивается снизу контактами к основной плате. В таком положении приёмник можно настраивать, а при крайней необходимости переднюю и заднюю платы несложно отпаять.


Рис. 4. Вид снизу на монтаж радиоприемника.

Наконец, после окончательной настройки на диапазон выравнивают положение плат друг относительно друга (под углом 90˚) и припаивают уголки. «Крону» можно прикрепить к основной плате двусторонним скотчем.

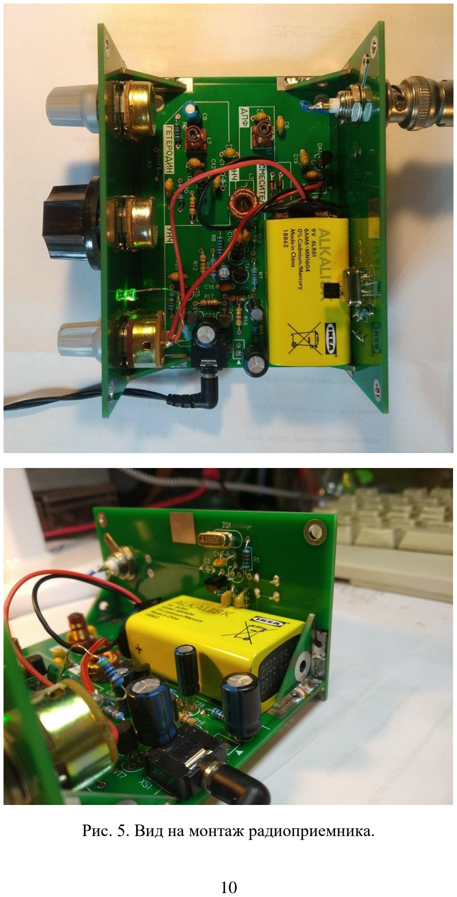
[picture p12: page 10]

Рис. 5. Вид на монтаж радиоприемника.

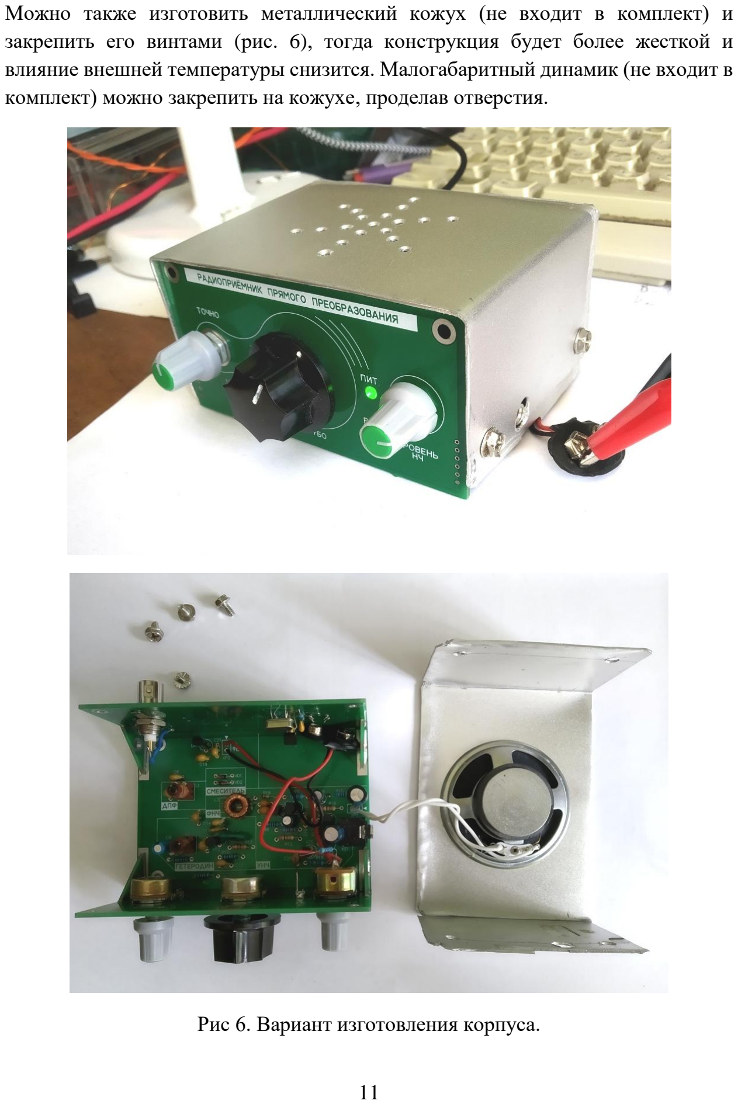
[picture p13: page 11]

Можно также изготовить металлический кожух (не входит в комплект) и закрепить его винтами (рис. 6), тогда конструкция будет более жесткой и влияние внешней температуры снизится. Малогабаритный динамик (не входит в комплект) можно закрепить на кожухе, проделав отверстия.

Рис 6. Вариант изготовления корпуса.

Благодарим вас за внимание к нашему проекту! Желаем получить удовольствие от сборки и наладки приемника. 73!

С любыми вопросами обращайтесь:

Влад Жигалов (R2DNN) zhigalov@gmail.com

Герман Антошкин (R3YAB) r3yab@mail.ru

Радиоклуб МИЭТ (RK3AZB) https://vk.com/rk3azb

Литература:

1. В.Т. Поляков. Радиолюбителям о технике прямого преобразования (1990). http://qrp.ru/files/literature/category/10-ra3aaedocs?download=247%3Adc
2. В.Т. Поляков. Приемник прямого преобразования для "охоты на лис", журнал "Радио" за 1982 год, №4, стр. 49-52; №7, стр.54, 55. http://qrp.ru/files/literature/category/10-ra3aaedocs?download=376%3Afoxhuntdcrra3aae (http://qrp.ru/files/literature/category/10-ra3aaedocs?download=376%3Afoxhuntdcrra3aae)
3. Д. Горох. Применение сердечников из аморфного железа. CQ-QRP#70 (Весна 2020). http://qrp.ru/cqqrp-magazine/1536-cq-qrp-70
4. Тема про данный приёмник на форуме клуба RU-QRP: RU-QRP Club forum :: Тема: Приёмник ППП радиоклуба МИЭТ (http://qrp.ru/forum/9-%D0%A1%D0%B0%D0%BC%D0%BE%D0%B4%D0%B5%D0%BB%D1%8C%D0%BD%D0%B0%D1%8F-%D1%82%D0%B5%D1%85%D0%BD%D0%B8%D0%BA%D0%B0/13210-%D0%9F%D1%80%D0%B8%D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)

Приложение. Перечень элементов

Обозначение | Номинал | Описание | Кол-во
C1, C2 | 180 или 220 | Конденсатор керамический | 2
C11, C16 | 0.01мк | Конденсатор керамический | 2
C12 | 180 | Конденсатор керамический М1500 | 1
C14 | 150 | Конденсатор керамический NP0 | 1
C13 | 0,047мк | Конденсатор керамический | 1
C15 | 4700 | Конденсатор керамический М1500 | 1
C17 | 47мк | Конденсатор электролитический | 1
C22, C23 | 470мк | Конденсатор электролитический | 2
C3 | 10 | Конденсатор керамический | 1
C4, C7, C9, C10, C19, C20, C21, C24 | 0.1мк | Конденсатор керамический | 8
C5 | 100 | Конденсатор керамический | 1
C6 | 22 | Конденсатор керамический | 1
C8 | 10мк | Конденсатор электролитический | 1
C18 | 100мк | Конденсатор электролитический | 1
DA1 | 78L06 | Стабилизатор напряжения | 1
L1, L2 | - | Катушка индуктивности подстроечная | 2
L3 | - | Катушка индуктивности | 1
R1 | 15к | Резистор | 1
R11, R12, R13, R17 | 2к | Резистор | 4
R15 | 470 | Резистор | 1
R16 | 4.7к | Резистор | 1
R18 | 1М или 2М | Резистор | 1
R19 | 47 | Резистор | 1
R2, R3, R8 | 1к | Резистор | 3
R4 | 1к | Резистор переменный | 1
R5, R14 | 10к | Резистор переменный c выключателем | 2
R6, R10 | 100к | Резистор | 2
R7 | 20к | Резистор | 1
R9 | 200к | Резистор | 1
SB1 | KLS7-TS6601 | Кнопка тактовая | 1
VD1, VD2 | 1N4148 | Диод | 2
VD3, VD4 | BB133 | Варикап | 2
VT1, VT3, VT4, VT5, VT6 | BC547 | Транзистор биполярный | 5
VT2, VT7 | BC557 | Транзистор биполярный | 2
XP1, XP2* | PLS-2 | Вилка штыревая | 2
XS1 | PJ-307 | Розетка | 1
XT1* | DG128-5.0-02P-14 | Соединитель | 1
ZQ1 | 7 MHz | Резонатор кварцевый | 1
* - не комплектуются

Дополнительно: розетка BNC, рукоятки малые (2 шт), рукоятка большая, колодка батарейная, светодиод, резистор 4,7к для светодиода.

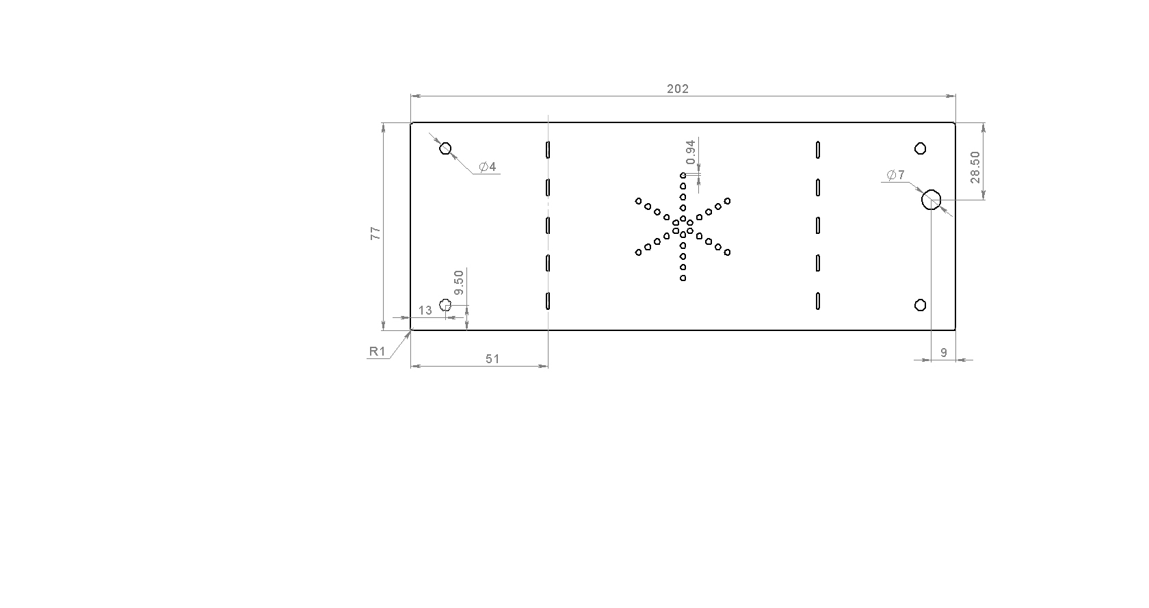
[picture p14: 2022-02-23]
Models/Кожух.JPG

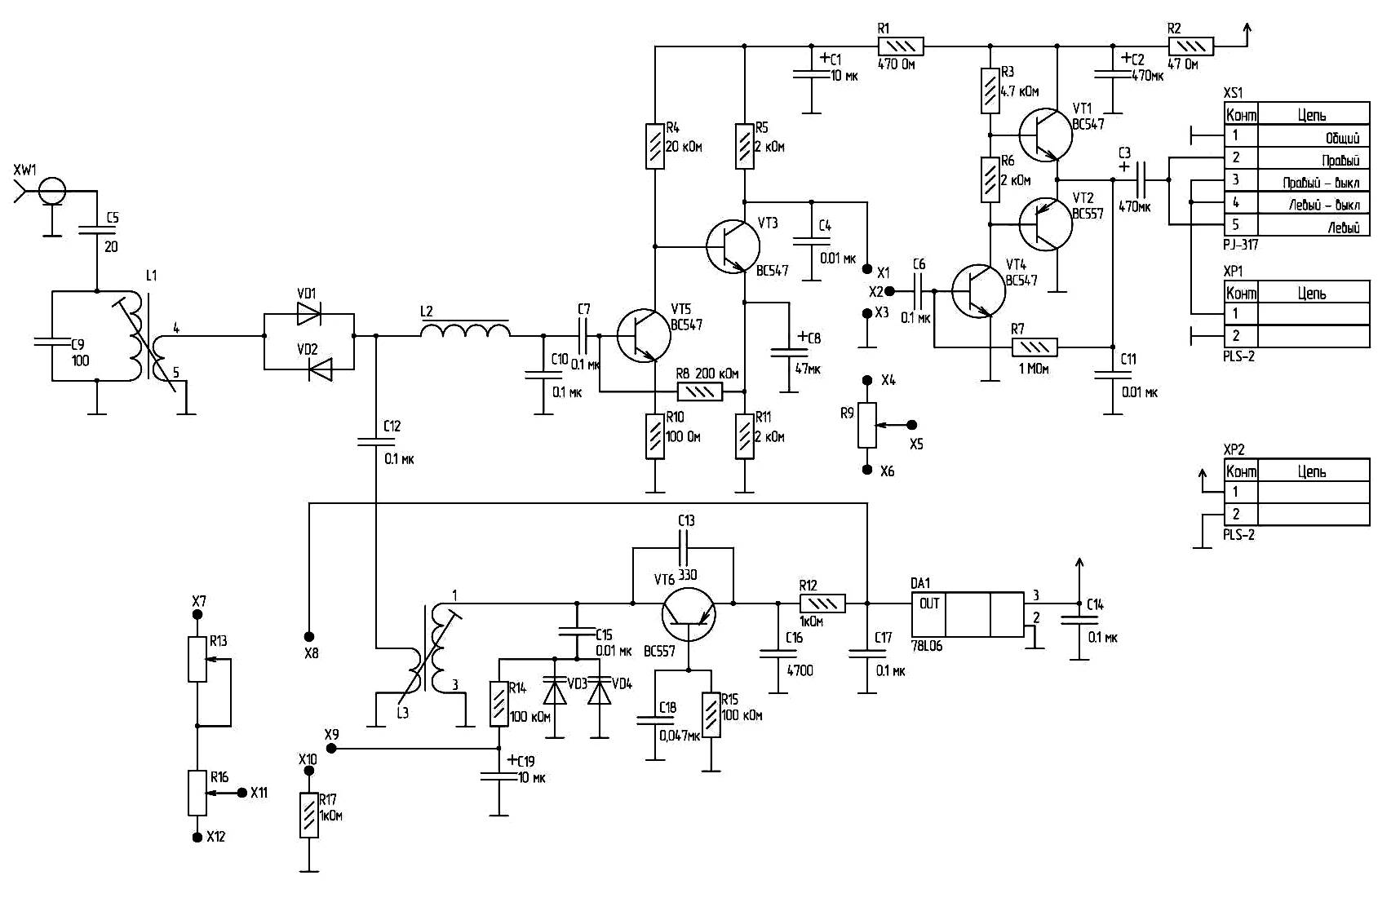
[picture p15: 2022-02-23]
Bottom/Э3.jpg

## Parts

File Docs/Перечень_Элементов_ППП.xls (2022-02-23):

Designator | Comment | Description | Quantity | Footprint | LibRef | *20
C1, C2 | 150 | Конденсатор керамический | 2 | К10-17Б | C_К10-17Б | 40
C11, C16 | 0.01 мк | Конденсатор керамический | 2 | К10-17Б | C_К10-17Б | 40
C12, C14 - М470 | 330 | Конденсатор керамический | 2 | К10-17Б | C_К10-17Б | 40
C13 | 0,047мк | Конденсатор керамический | 1 | К10-17Б | C_К10-17Б | 20
C15 - NP0 | 4700 | Конденсатор керамический | 1 | К10-17Б | C_К10-17Б | 20
C17 | 47мк | Конденсатор электролитический | 1 | К50-35 | K50-35 | 20
C22, C23 | 470мк | Конденсатор электролитический | 2 | К50-35 | K50-35 | 40 | другой размер
C3 | 10 | Конденсатор керамический | 1 | К10-17Б | C_К10-17Б | 20
C4, C7, C9, C10, C19, C20, C21 | 0.1 мк | Конденсатор керамический | 7 | К10-17Б | C_К10-17Б | 140
C5 | 100 | Конденсатор керамический | 1 | К10-17Б | C_К10-17Б | 20
C6 | 20 | Конденсатор керамический | 1 | К10-17Б | C_К10-17Б | 20
C8, C18 | 10 мк | Конденсатор электролитический | 2 | К50-35 | K50-35 | 40
DA1 | 78L06 | Стабилизатор | 1 | КТ-26 | 78L06 | 20
L1, L2 | Trim_coil_2 | Катушка индуктивности подстроечная | 2 | trim_coil | Trim_coil_2 | 40 | 23р
L3 | T50-6 | Катушка индуктивности | 1 | T50-6 | T50-6 | 20
R1 | 15 к | Резистор | 1 | С1-4 | R_C1-4 | 20
R11, R12, R13, R17 | 2 кОм | Резистор | 4 | С1-4 | R_C1-4 | 80
R15 | 470 Ом | Резистор | 1 | С1-4 | R_C1-4 | 20
R16 | 4.7 кОм | Резистор | 1 | С1-4 | R_C1-4 | 20
R18 | 1 МОм | Резистор | 1 | С1-4 | R_C1-4 | 20
R19 | 47 Ом | Резистор | 1 | С1-4 | R_C1-4 | 20
R2, R3, R8 | 1кОм | Резистор | 3 | С1-4 | R_C1-4 | 60
R4 | 1к | Резистор переменный | 1 | WH148R | WH148 | 20
R5, R14*- c выключателем | 10к | Резистор переменный | 2 | WH148R | WH148 | 40
R6, R10 | 100 кОм | Резистор | 2 | С1-4 | R_C1-4 | 40
R7 | 20 кОм | Резистор | 1 | С1-4 | R_C1-4 | 20
R9 | 200 кОм | Резистор | 1 | С1-4 | R_C1-4 | 20
SB1 | KLS7-TS6601 | Кнопка тактовая | 1 | KLS7-TS6601 | KLS7-TS6601 | 20
VD1, VD2 | 1N4148 | Диод | 2 | DO35 | 1N4148 | 40
VD3, VD4 | BB133 | Варикап | 2 | SOD323 | BB133 | 40
VT1, VT3, VT4, VT5, VT6 | BC547 | Транзистор биполярный | 5 | КТ-26 | BC547 | 100
VT2, VT7 | BC557 | Транзистор биполярный | 2 | КТ-26 | BC557 | 40
XP1, XP2* - не комплектовать | PLS-2 | Вилка штыревая | 2 | PLS-2 | PLS-2 | 40
XS1 | PJ-307 | Розетка | 1 | PJ-307 | PJ-307 | 20
XT1* - не комплектовать | DG128-5.0-02P-14 | Соединитель | 1 | DG128-5.0-02P-14 | DG128-5.0-02P-14 | 20
ZQ1 | 7 MHz | Резонатор кварцевый | 1 | HC-49U | HC-49U | 20 | 11р
Доп
BNC
Рукоятки мелкие*2 | Али/ебай | ЧИД
колодка для кроны | Технобур
рукоятка 30 мм
Led

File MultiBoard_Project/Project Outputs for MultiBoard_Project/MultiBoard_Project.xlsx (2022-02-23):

Comment | Description | Designator | Footprint | LibRef | Quantity
220 |  | C1, C2 | К10-17Б | C_К10-17Б | 2
100 |  | C1, C7 | К10-17Б | C_К10-17Б | 2
20 |  | C2 | К10-17Б | C_К10-17Б | 1
0.1 мк |  | C3 | К10-17Б | C_К10-17Б | 1
0,1мк |  | C3, C5, C6, C16, C17, C18 | К10-17Б | C_К10-17Б | 6
10мк |  | C4 | К50-35 | K50-35 | 1
180 |  | C8* | К10-17Б | C_К10-17Б | 1
0,047мк |  | C9 | К10-17Б | C_К10-17Б | 1
150 |  | C10** | К10-17Б | C_К10-17Б | 1
4700 |  | C11 | К10-17Б | C_К10-17Б | 1
0,1 мк |  | C12 | К10-17Б | C_К10-17Б | 1
0,01мк |  | C13 | К10-17Б | C_К10-17Б | 1
47мк |  | C14 | К50-35 | K50-35 | 1
100мк |  | C15 | К50-35 | K50-35 | 1
470мк |  | C20, C22 | К50-35 | K50-35 | 2
78L06 |  | DA1 | КТ-26 | 78L06 | 1
GNL-3012ED |  | HL1 | GNL-3012ED | GNL-3012ED | 1
Trim_coil_2 |  | L1, L2 | trim_coil | Trim_coil_2 | 2
T50-6 |  | L3 | T50-6 | T50-6 | 1
3,3к |  | R1 | С1-4 | R_C1-4 | 1
15 к |  | R1 | С1-4 | R_C1-4 | 1
1 к |  | R2 | С1-4 | R_C1-4 | 1
1к |  | R2, R7 | С1-4 | R_C1-4 | 2
1к |  | R3 | WH148R | WH148 | 1
10к |  | R4, R13 | WH148R | WH148 | 2
100к |  | R5, R9 | С1-4 | R_C1-4 | 2
20к |  | R6 | С1-4 | R_C1-4 | 1
200к |  | R8 | С1-4 | R_C1-4 | 1
2к |  | R10, R11, R12, R16 | С1-4 | R_C1-4 | 4
470 |  | R14 | С1-4 | R_C1-4 | 1
4,7к |  | R15 | С1-4 | R_C1-4 | 1
1М |  | R17 | С1-4 | R_C1-4 | 1
47 |  | R18 | С1-4 | R_C1-4 | 1
4.7кОм |  | R19 | С1-4 | R_C1-4 | 1
51к |  | R20 | С1-4 | R_C1-4 | 1
KLS7-TS6601 |  | SB1 | KLS7-TS6601 | KLS7-TS6601 | 1
1N4148 | Диод | VD1, VD2 | DO35 | 1N4148 | 2
BB133 | VHF variable capacitance diode | VD3 | SOD323 | BB133 | 1
BC547 |  | VT1, VT2, VT3, VT4, VT5 | КТ-26 | BC547 | 5
BC557 |  | VT1, VT6 | КТ-26 | BC557 | 2
PLS-2 |  | XP1, XP2 | PLS-2 | PLS-2 | 2
PJ-307 |  | XS1 | PJ-307 | PJ-307 | 1
DG308-2.54-02P |  | XT1 | DG308-2.54-02P | DG308-2.54-02P | 1
HC-49U |  | ZQ1 | HC-49U | HC-49U | 1

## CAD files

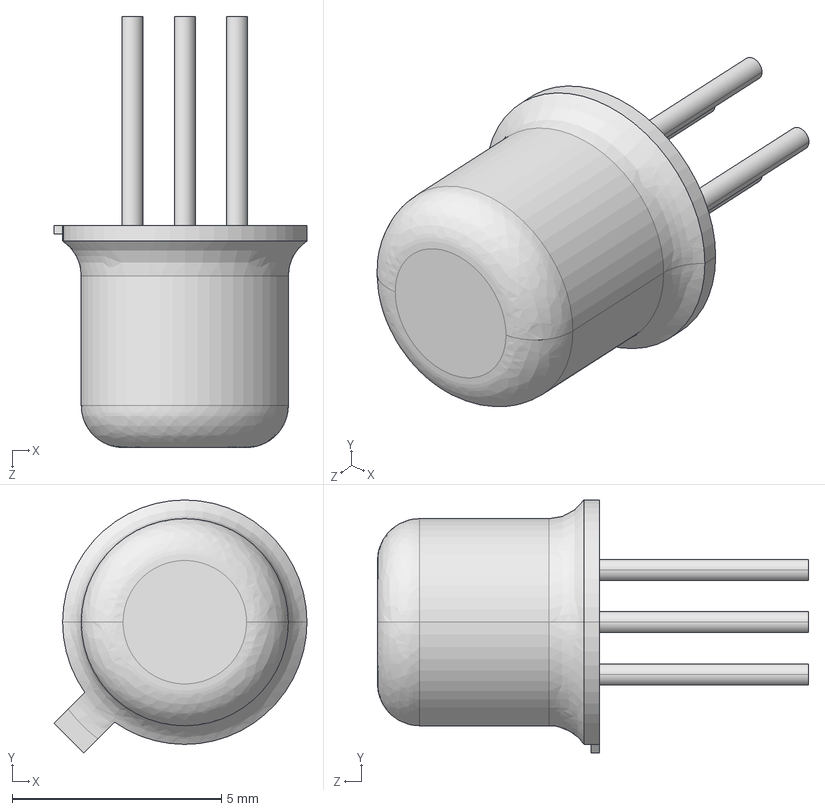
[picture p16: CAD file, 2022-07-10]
Freq_meter_PPP/User_Library-KT-112.step
6.05 x 6.05 x 10.3 mm

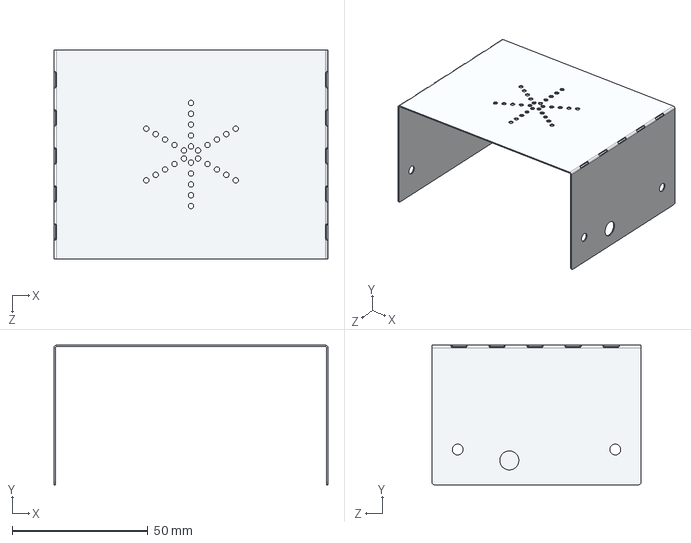
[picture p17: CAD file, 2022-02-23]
Models/Кожух.STEP
100.8 x 51.4 x 77.0 mm

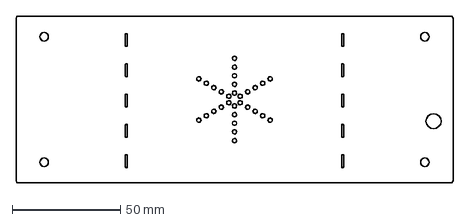
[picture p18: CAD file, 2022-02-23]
Models/Развертка - Кожух.DXF
202.0 x 77.0 mm

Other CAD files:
Models/Кожух.SLDDRW
Models/Кожух.SLDPRT

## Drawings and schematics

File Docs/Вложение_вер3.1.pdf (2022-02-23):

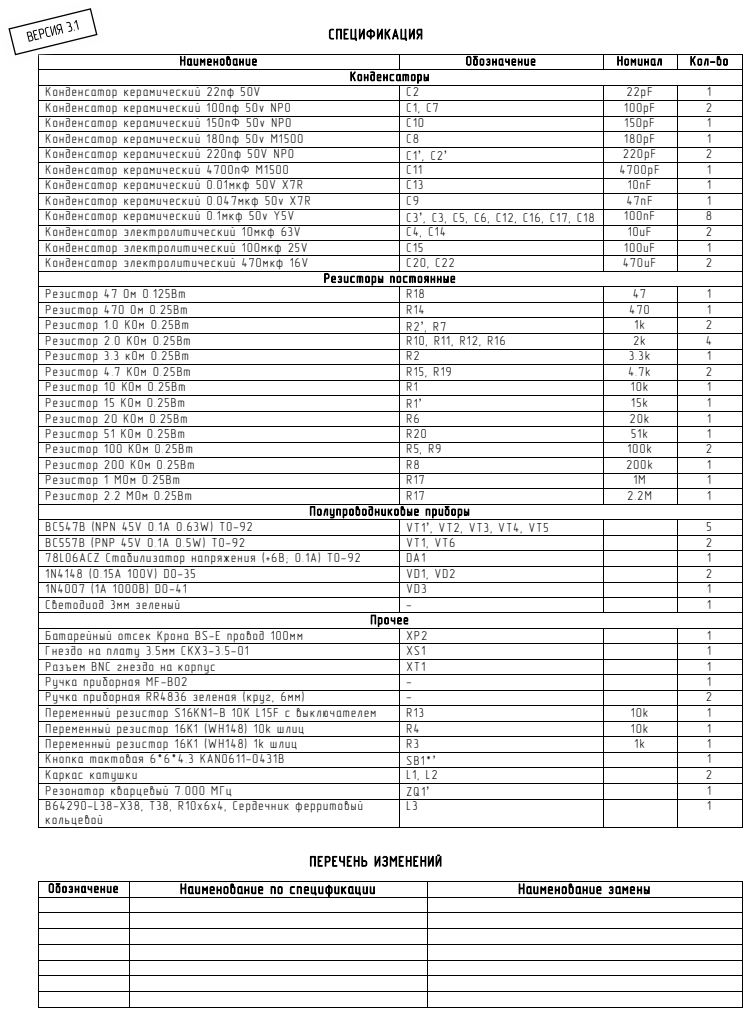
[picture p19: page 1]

Конденсатор керамический 22пф 50V | C2 | 22pF | 1
Конденсатор керамический 100пф 50v NPO | C1, C7 | 100pF | 2
Конденсатор керамический 150пФ 50v NPO | C10 | 150pF | 1
Конденсатор керамический 180пф 50v М1500 | C8 | 180pF | 1
Конденсатор керамический 220пф 50V NPO | C1’, C2’ | 220pF | 2
Конденсатор керамический 4700пФ М1500 | C11 | 4700pF | 1
Конденсатор керамический 0.01мкф 50V X7R | C13 | 10nF | 1
Конденсатор керамический 0.047мкф 50v X7R | C9 | 47nF | 1
Конденсатор керамический 0.1мкф 50v Y5V | C3’, C3, C5, C6, C12, C16, C17, C18 | 100nF | 8
Конденсатор электролитический 10мкф 63V | C4, C14 | 10uF | 2
Конденсатор электролитический 100мкф 25V | C15 | 100uF | 1
Конденсатор электролитический 470мкф 16V | C20, C22 | 470uF | 2

Резистор 47 Ом 0.125Вт | R18 | 47 | 1
Резистор 470 Ом 0.25Вт | R14 | 470 | 1
Резистор 1.0 КОм 0.25Вт | R2’, R7 | 1k | 2
Резистор 2.0 КОм 0.25Вт | R10, R11, R12, R16 | 2k | 4
Резистор 3.3 кОм 0.25Вт | R2 | 3.3k | 1
Резистор 4.7 КОм 0.25Вт | R15, R19 | 4.7k | 2
Резистор 10 КОм 0.25Вт | R1 | 10k | 1
Резистор 15 КОм 0.25Вт | R1’ | 15k | 1
Резистор 20 КОм 0.25Вт | R6 | 20k | 1
Резистор 51 КОм 0.25Вт | R20 | 51k | 1
Резистор 100 КОм 0.25Вт | R5, R9 | 100k | 2
Резистор 200 КОм 0.25Вт | R8 | 200k | 1
Резистор 1 МОм 0.25Вт | R17 | 1M | 1
Резистор 2.2 МОм 0.25Вт | R17 | 2.2M | 1

BC547B (NPN 45V 0.1A 0.63W) TO-92 | VT1’, VT2, VT3, VT4, VT5 | 5
BC557B (PNP 45V 0.1A 0.5W) TO-92 | VT1, VT6 | 2
78L06ACZ Стабилизатор напряжения (+6В; 0.1А) TO-92 | DA1 | 1
1N4148 (0.15A 100V) DO-35 | VD1, VD2 | 2
1N4007 (1А 1000В) DO-41 | VD3 | 1
Светодиод 3мм зеленый | - | 1

Батарейный отсек Крона BS-E провод 100мм | XP2 | | 1
Гнездо на плату 3.5мм CKX3-3.5-01 | XS1 | | 1
Разъем BNC гнездо на корпус | XT1 | | 1
Ручка приборная MF-B02 | - | | 1
Ручка приборная RR4836 зеленая (круг, 6мм) | - | | 2
Переменный резистор S16KN1-B 10K L15F с выключателем | R13 | 10k | 1
Переменный резистор 16K1 (WH148) 10k шлиц | R4 | 10k | 1
Переменный резистор 16K1 (WH148) 1k шлиц | R3 | 1k | 1
Кнопка тактовая 6*6*4.3 KAN0611-0431B | SB1*’ | | 1
Каркас катушки | L1, L2 | | 2
Резонатор кварцевый 7.000 МГц | ZQ1’ | | 1
B64290-L38-X38, T38, R10х6х4, Сердечник ферритовый кольцевой | L3 | | 1

СХЕМА ЭЛЕКТРИЧЕСКАЯ ПРИНЦИПИАЛЬНАЯ

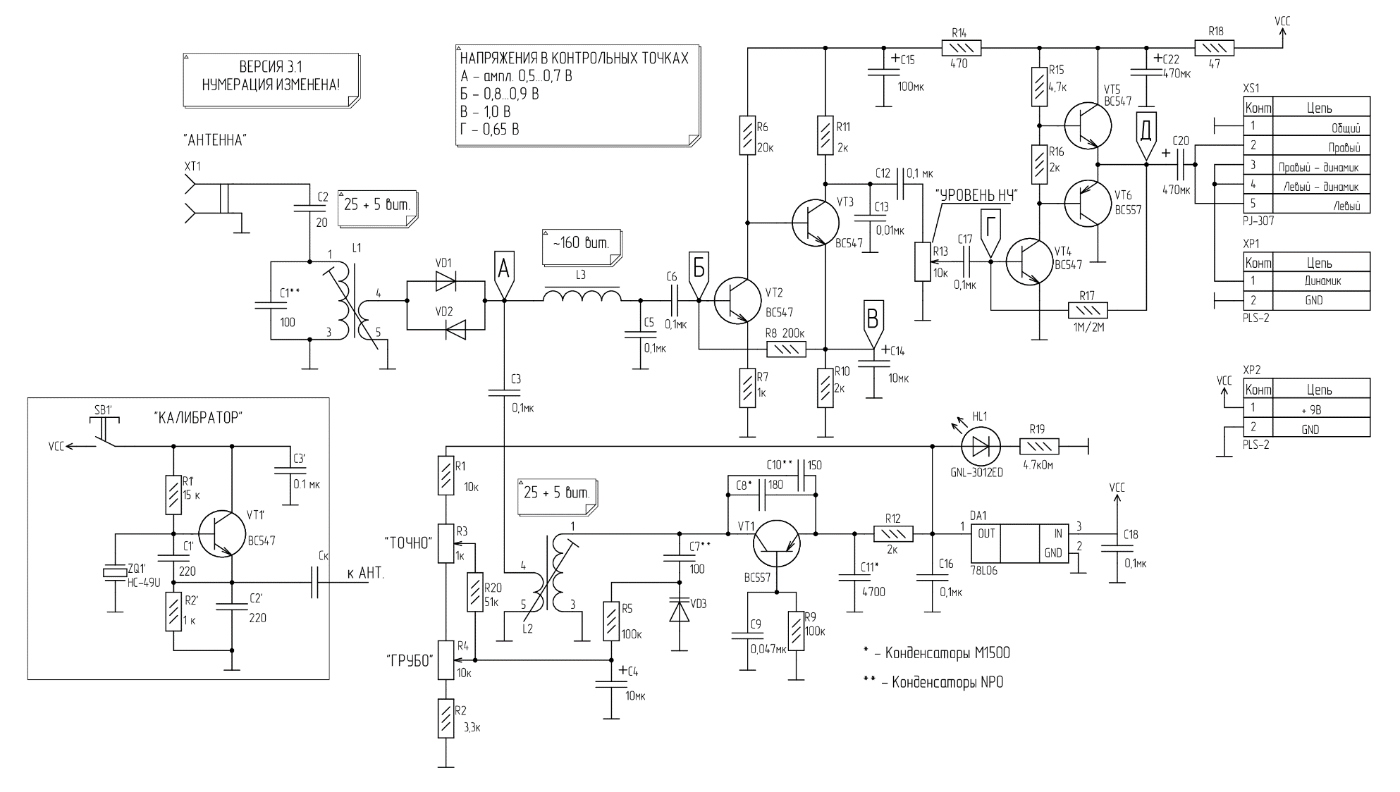
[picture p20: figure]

РАДИОКЛУБ МИЭТ г.ЗЕЛЕНОГРАД | 73 DE RK3AZB!

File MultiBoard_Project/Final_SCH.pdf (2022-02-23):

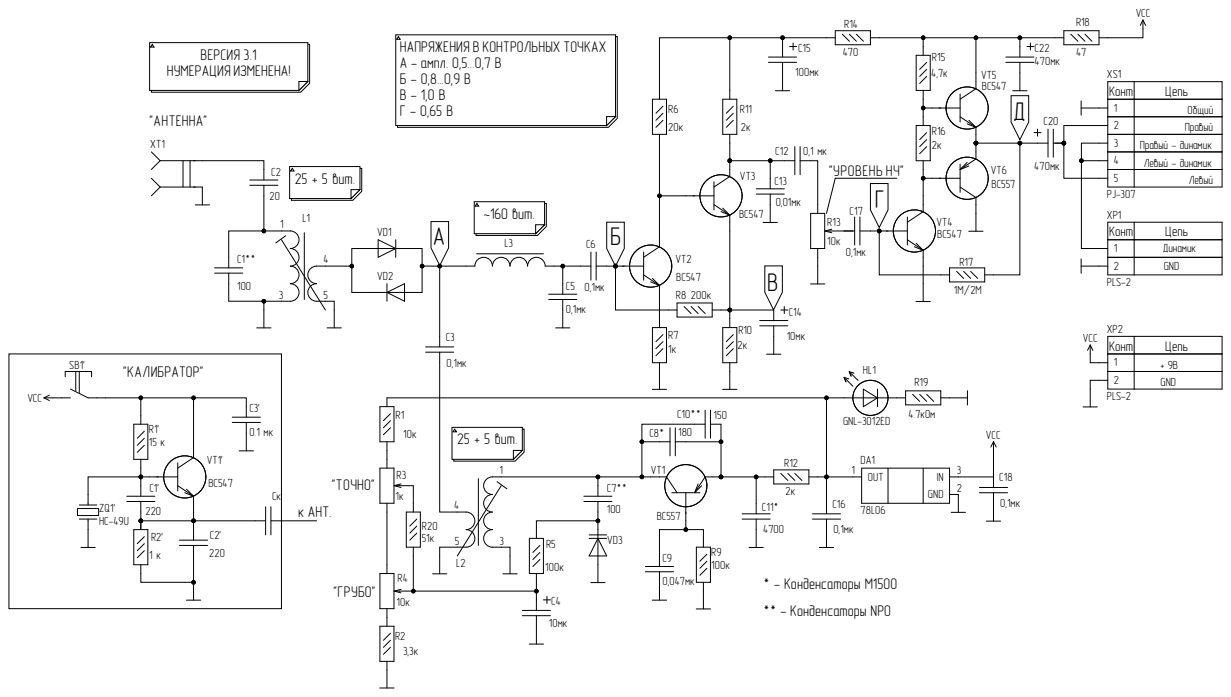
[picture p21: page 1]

Конт | Цепь

54321 | Пр а вый

Общи й

Пр а вый -д и н ами к
Ле вый -д и н ами к

Ле вый

21 | Ди н ами к

GND

OUT | IN GND

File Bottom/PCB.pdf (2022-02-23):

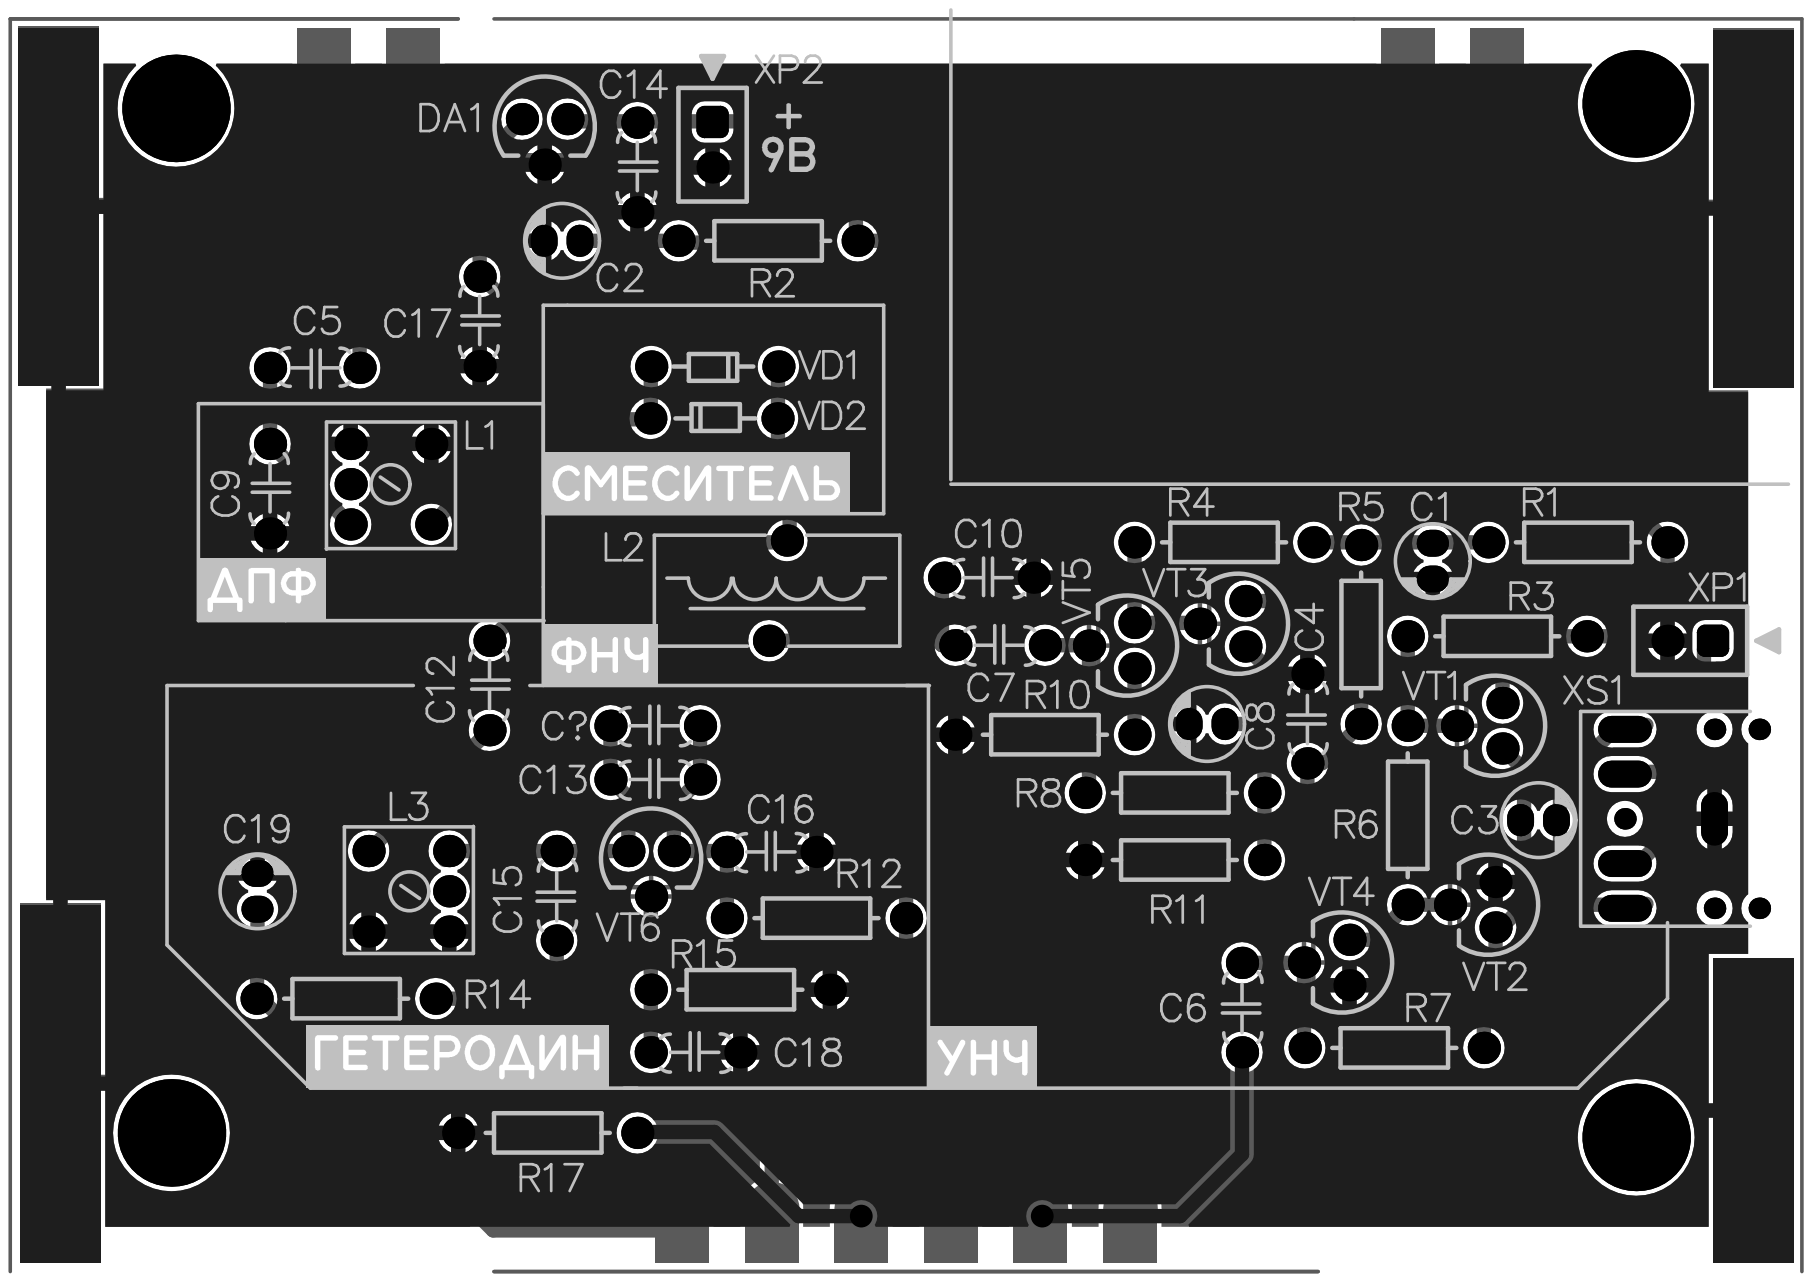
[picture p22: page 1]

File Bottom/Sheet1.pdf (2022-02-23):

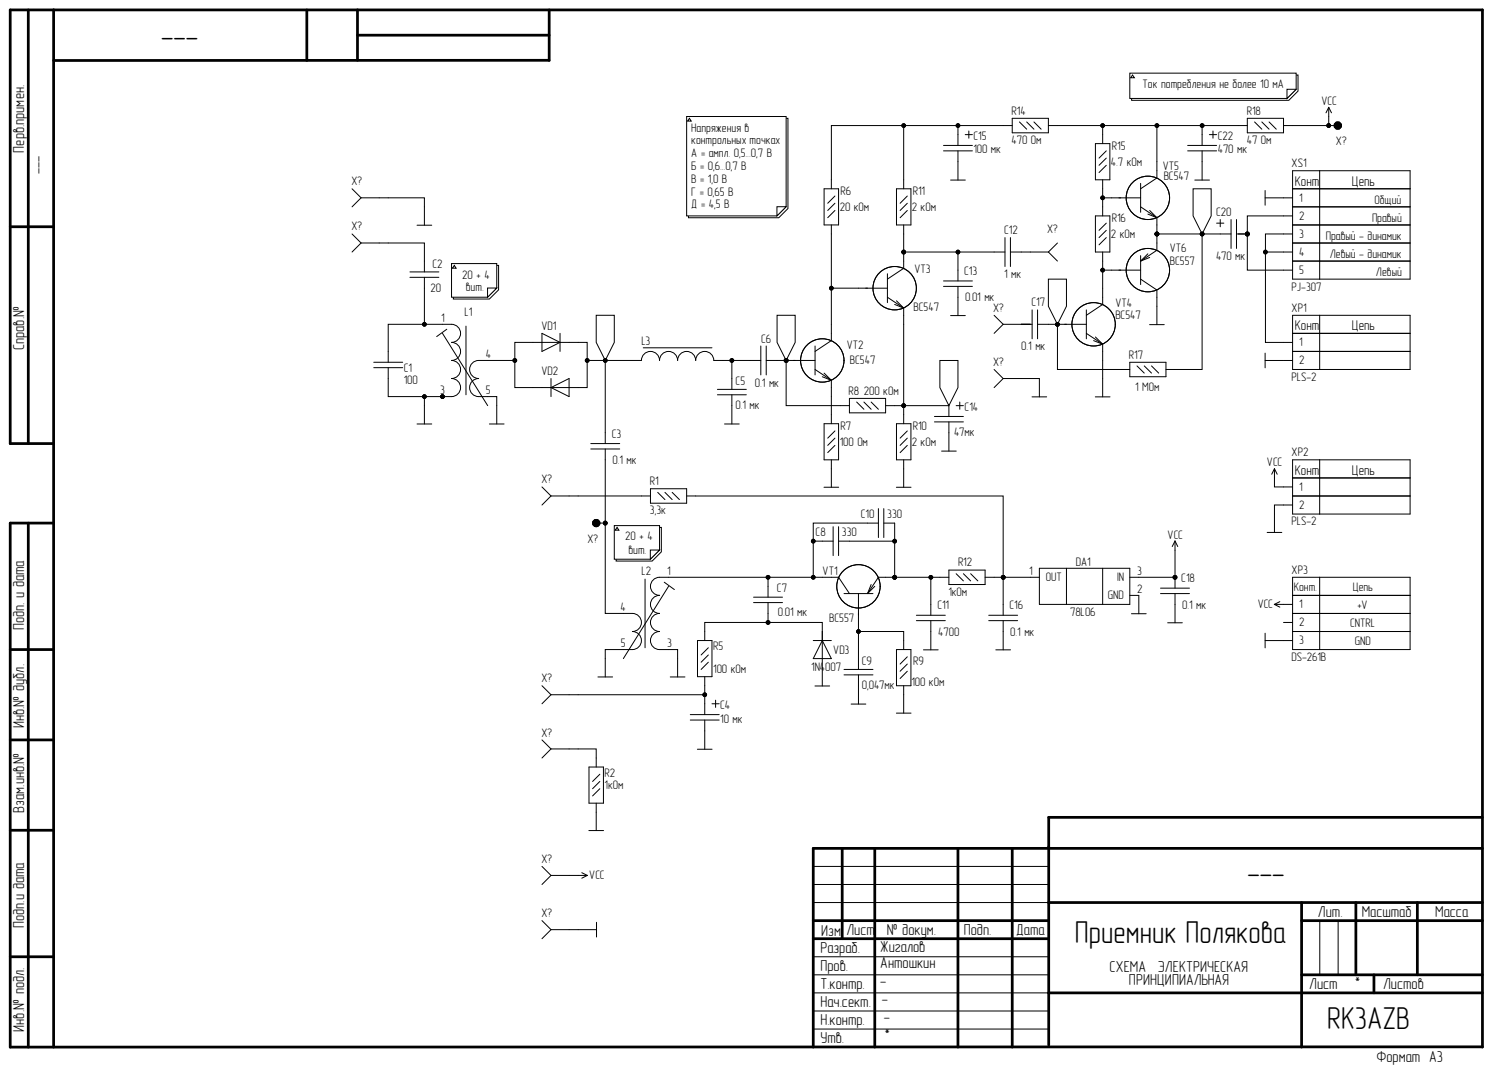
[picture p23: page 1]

Ток потребления не более 10 мА

Конт | Цепь
1 | Общий
2 | Правый
3 | Правый - динамик
4 | Левый - динамик
5 | Левый

Инв.№ подл. Подп.и дата Взам.инв.№ Инв.№ дубл. Подп. и дата

Конт. | Цепь
1 | +V
2 | CNTRL
3 | GND

Приемник Полякова СХЕМА ЭЛЕКТРИЧЕСКАЯ ПРИНЦИПИАЛЬНАЯ | Лит. | Масштаб | Масса
Изм. | Лист | № докум. | Подп. | Дата
Разраб. | | Жигалов
Пров. | | Антошкин
Т.контр. | - | | | | Лист * | Листов
Нач.сект. | - | | | | RK3AZB
Н.контр. | -
Утв. | *

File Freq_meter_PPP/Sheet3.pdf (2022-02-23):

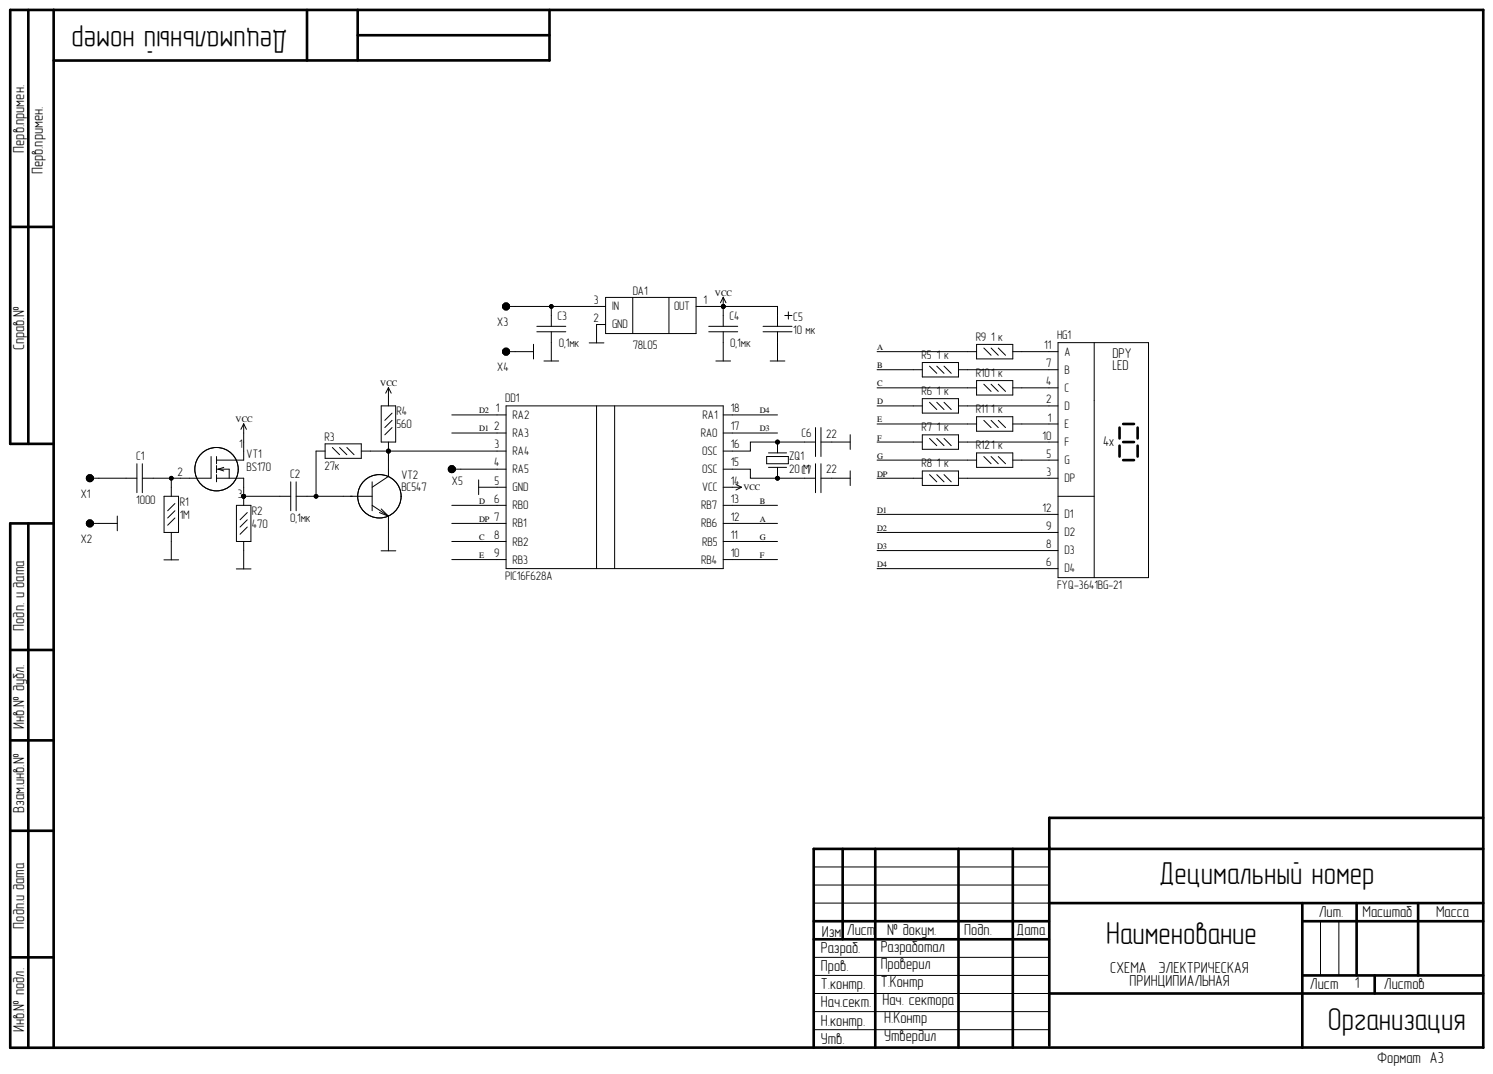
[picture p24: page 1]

D A 1 V C C
IN G N D | O U T

Инв.№ подл. Подп.и дата Взам.инв.№ Инв.№ дубл. Подп. и дата

Наименовани е СХЕМА ЭЛЕКТРИЧЕСКА Я ПРИНЦИПИА Л Ь Н А Я | . | Масштаб | Масса
Изм | . Лист | № докум . | Подп . | Дата | | Лист Лит

Разраб . | | Разработал
Пров . | | Проверил Т.Контр
Т .контр . | | | | | | Листов
Нач .сект . | Нач. сектора | | | | Организация
Н .контр . | Утвердил Н.Контр
Утв .

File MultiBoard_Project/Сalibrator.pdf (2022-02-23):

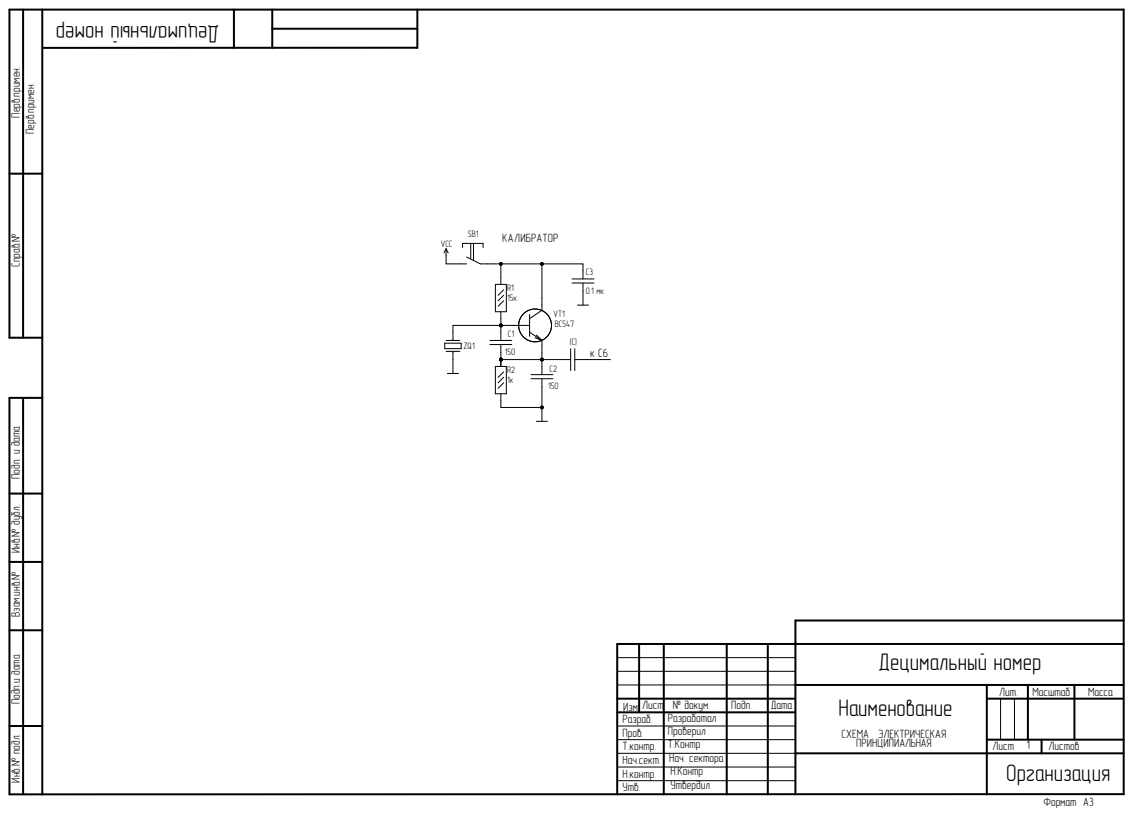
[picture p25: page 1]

Инв.№ подл. Подп.и дата Взам.инв.№ Инв.№ дубл. Подп. и дата

Децимальный номер

Наименование СХЕМА ЭЛЕКТРИЧЕСКАЯ ПРИНЦИПИАЛЬНАЯ | Лит. | Масштаб | Масса
Изм. | Лист | № докум. | Подп. | Дата
Разраб. | | Разработал
Пров. | | Проверил
Т.контр. | Т.Контр | | | | Лист 1 | Листов
Нач.сект. | Нач. сектора | | | | Организация
Н.контр. | Н.Контр
Утв. | Утвердил

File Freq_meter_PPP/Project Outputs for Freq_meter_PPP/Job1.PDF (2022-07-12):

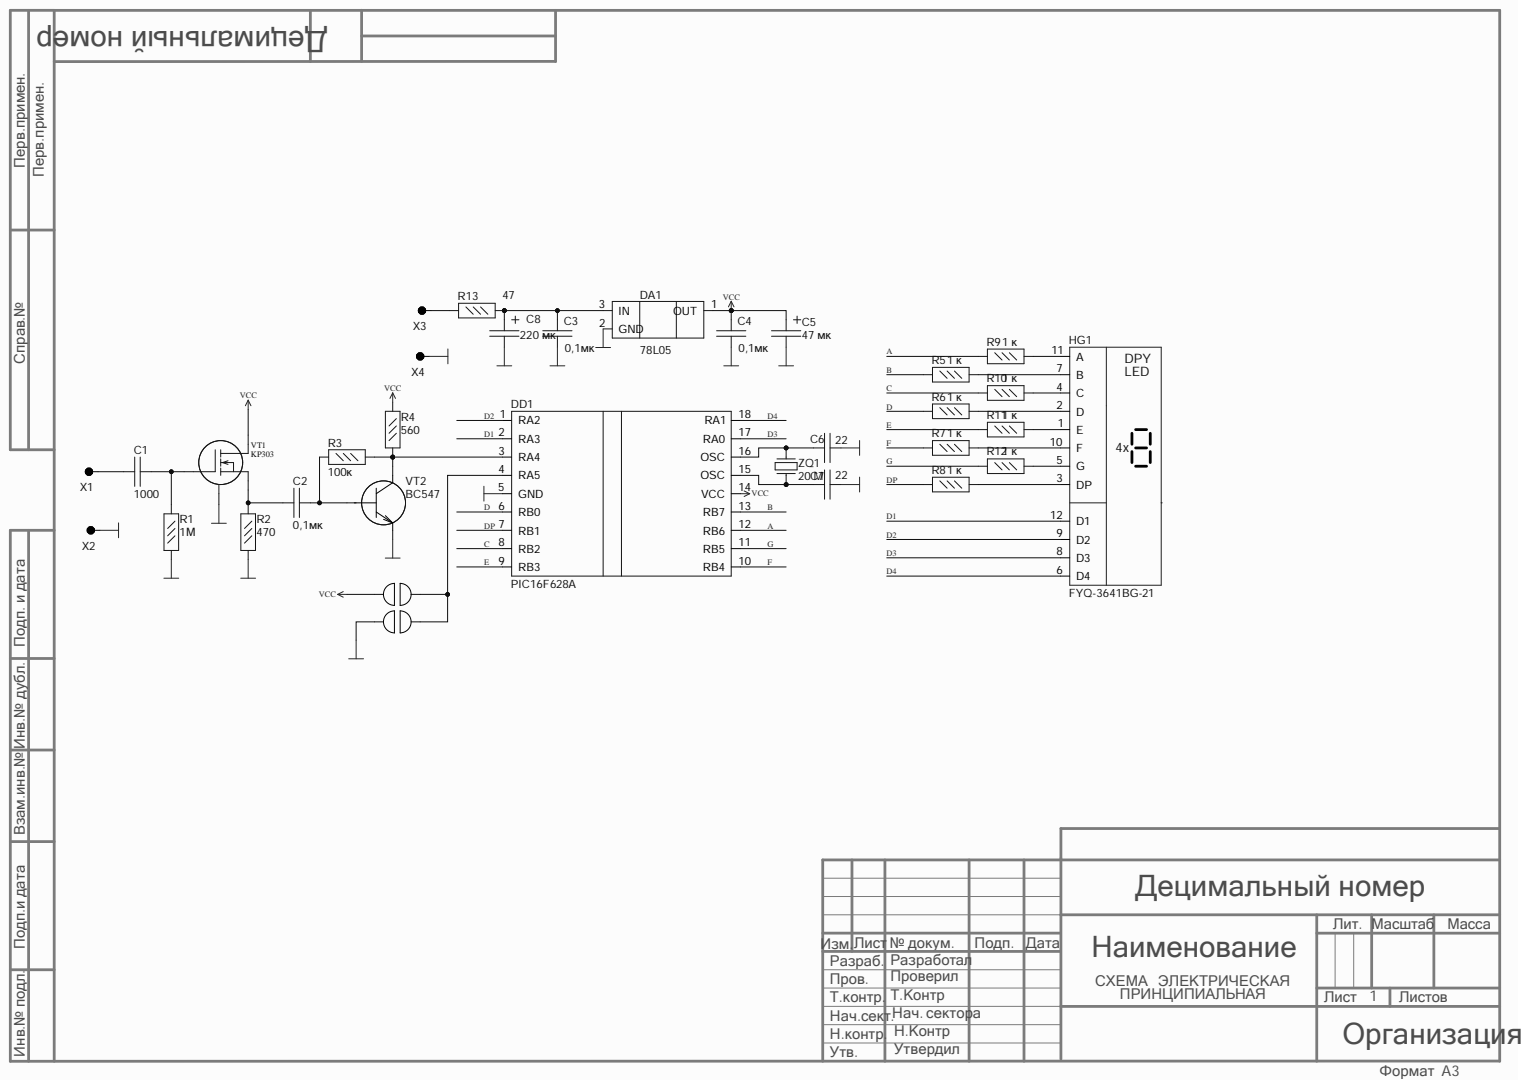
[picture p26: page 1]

DA 1 VCC
IN GN D | OU | T

Инв.№ подл. Подп.и дата Взам.инв.№ Инв.№ дубл. Подп. и дата

Наименование СХЕМА ЭЛЕКТРИЧЕСКАЯ ПРИНЦИПИА Л Ь Н А Я | Лит . | б Масшт а | Масс а

Изм | Лис т . | № докум . | Подп . | Дат а
Разра б . | | Разраб о т а л
Про в . | | Пров е р и л
Т .контр | . Т .Конт р | | | | Лис т | Лист о в
Нач .сек | Нач. сектора т .
Н .конт р | Н .Кон т р .
Утв . | Утверд и л

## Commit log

2022-02-24 del trash
    [Front.PrjPcb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]
2022-07-10 Версия платы 1.1: изменен корпус КП303, добавлена RC цепочка
    [Freq_meter_PPP.PrjPcb, KP303.PcbLib, KP303.SchLib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]
2022-07-10 Версия платы 1.1
    [PCB3.PcbDoc, Sheet3.SchDoc]
2022-07-11 Версия 1.1
    [Freq_meter_PPP.PrjPcb, PCB3.PcbDoc, Sheet3.SchDoc]
